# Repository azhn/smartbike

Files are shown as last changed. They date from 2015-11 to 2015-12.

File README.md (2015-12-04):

SMARTBIKE
=====

BLEES
BLEES: Bluetooth Low Energy Environment Sensors.
<br /><br />
BLEES is a 1 inch round sensor tag for sensing the ambient environment. It monitors
temperature, humidity, light, pressure, and movement and reports its readings
over BLE.
<br /><br /><br />

Hardware
--------
The BLEES hardware is a small, once inch round sensor board that mounts onto a [Squall](https://github.com/helena-project/squall) BLE sensor tag. The board 
currently has four sensors:

1. Temperature and Humidity
2. Pressure
3. Light
4. Accelerometer

The BLEES hardware is located in the `hardware` directory, where you can find
the Eagle design files.

Software
--------
The [Squall](https://github.com/helena-project/squall) uses the software located 
in the `software` directory. Follow the directions at [Lab11's Wiki](http://lab11.eecs.umich.edu/wiki/doku.php?id=eecs582w15:setup:start) to 
get your machine set up to build and flash the Squall.

The software sends out the data from the BLEES sensors in BLE advertisements. Specifically,
we encode the data in the "manufacturer data" section of a BLE advertisement and scan response packet.
This means that we do not have to establish a connection between the Squall and a scanning device, 
saving energy by not requiring any devices to pair with the BLEES device, and allowing us to send
the sensor data to many different scanning devices at once.

[Here's a useful BLE Advertisement primer](http://www.argenox.com/bluetooth-low-energy-ble-v4-0-development/library/a-ble-advertising-primer/)

Summon App
-----------
[Summon](https://github.com/lab11/summon) is a UI application for BLE devices.
Rather than requiring every user
to install a new app for every BLE device, Summon allows BLE devices to
point to their own HTML/JS based interface and loads it in a single
application. BLEES supports the summon architecture and provides
a Summon application.

Cloning
-------
To clone both this repository and the required submodules,
clone with the `--recursive` option: 
`git clone --recursive git@github.com:lab11/blees.git`

Otherwise, you can initialize the submodule and keep submodules up to
date by doing `git submodule update --init --recursive`.

If you think all of this is ridiculous and git should just handle submodules automatically, use this:
https://gist.github.com/brghena/fc4483a2df83c47660a5

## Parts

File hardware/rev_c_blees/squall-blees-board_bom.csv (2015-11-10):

# Bill of Materials
# Converted from squall-blees-board_bom.xlsx
# Generated by bom_to_text.py
Qty | Value | Device | Package | Parts | Description | DIGIKEY | MOUSER | NEWARK
5 | 100nF | CAPACITOR | 0402_CAP | C1, C2, C3, C4, C5 | 0402 Capacitor | 1276-1442-6-ND
1 | 10uF | CAPACITOR0603_CAP | 0603_CAP | C6 | 0603 Capacitor | 1276-1119-6-ND
1 | BLUE | LED0603 | LED-0603 | D1 | LEDs | 160-1647-1-ND
2 | SQUALL_HEADER | SQUALL_HEADER | SQUALL_HEADER | J1 | Header for a sensor board on top of the Squall BLE tag board. | H11617CT-ND
2 | HIROSE-DF40C-10DP-0.4V | HIROSE-DF40C-10DP-0.4V | 2X5/SMD/0.4MM | J2, J3 | DF40 Series Header - 0.4MM Pitch | H11616CT-ND | 798-DF40C10DP0.4V51 | 68X2585
1 | 1k | RESISTOR0402_RES | 0402_RES | R1 | 0402 Resistor | RHM1.0KCECT-ND
2 | 10k | RESISTOR0402_RES | 0402_RES | R2, R3 | 0402 Resistor | RHM10.0KCDCT-ND
1 | LPS331APQFN | LPS331APQFN | HCLGA-16L | U1 | LPS331AP pressure sensor |  |  | 52X6707
1 | TSL2561DFN | TSL2561DFN | DFN2 | U2 | TSL2561 light to digital converter | TSL2561-FNDKR-ND
1 | Si7021 | Si7021 | DFN | U3 | Si7021 temperature/humidity sensor | 336-2542-1-ND
1 | ADXL362 | ADXL362 | ADXL362 | U4 | Micropower 3-axis accelerometer | ADXL362BCCZ-R2DKR-ND

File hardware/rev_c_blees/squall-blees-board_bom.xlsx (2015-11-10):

 | Qty | Value | Device | Package | Parts | Description | DIGIKEY | MOUSER | NEWARK
b | 5 | 100nF | CAPACITOR | 0402_CAP | C1, C2, C3, C4, C5 | 0402 Capacitor | 1276-1442-6-ND
b | 1 | 10uF | CAPACITOR0603_CAP | 0603_CAP | C6 | 0603 Capacitor | 1276-1119-6-ND
l | 1 | BLUE | LED0603 | LED-0603 | D1 | LEDs | 160-1647-1-ND
b | 2 | SQUALL_HEADER | SQUALL_HEADER | SQUALL_HEADER | J1 | Header for a sensor board on top of the Squall BLE tag board. | H11617CT-ND
s | 2 | HIROSE-DF40C-10DP-0.4V | HIROSE-DF40C-10DP-0.4V | 2X5/SMD/0.4MM | J2, J3 | DF40 Series Header - 0.4MM Pitch | H11616CT-ND | 798-DF40C10DP0.4V51 | 68X2585
s | 1 | 1k | RESISTOR0402_RES | 0402_RES | R1 | 0402 Resistor | RHM1.0KCECT-ND
b | 2 | 10k | RESISTOR0402_RES | 0402_RES | R2, R3 | 0402 Resistor | RHM10.0KCDCT-ND
b | 1 | LPS331APQFN | LPS331APQFN | HCLGA-16L | U1 | LPS331AP pressure sensor |  |  | 52X6707
b | 1 | TSL2561DFN | TSL2561DFN | DFN2 | U2 | TSL2561 light to digital converter | TSL2561-FNDKR-ND
b | 1 | Si7021 | Si7021 | DFN | U3 | Si7021 temperature/humidity sensor | 336-2542-1-ND
b | 1 | ADXL362 | ADXL362 | ADXL362 | U4 | Micropower 3-axis accelerometer | ADXL362BCCZ-R2DKR-ND
 |  | (b)lees
 |  | (s)quall
 |  | (l)ed box
 |  | (o)bserver
 |  | (x) did not populate

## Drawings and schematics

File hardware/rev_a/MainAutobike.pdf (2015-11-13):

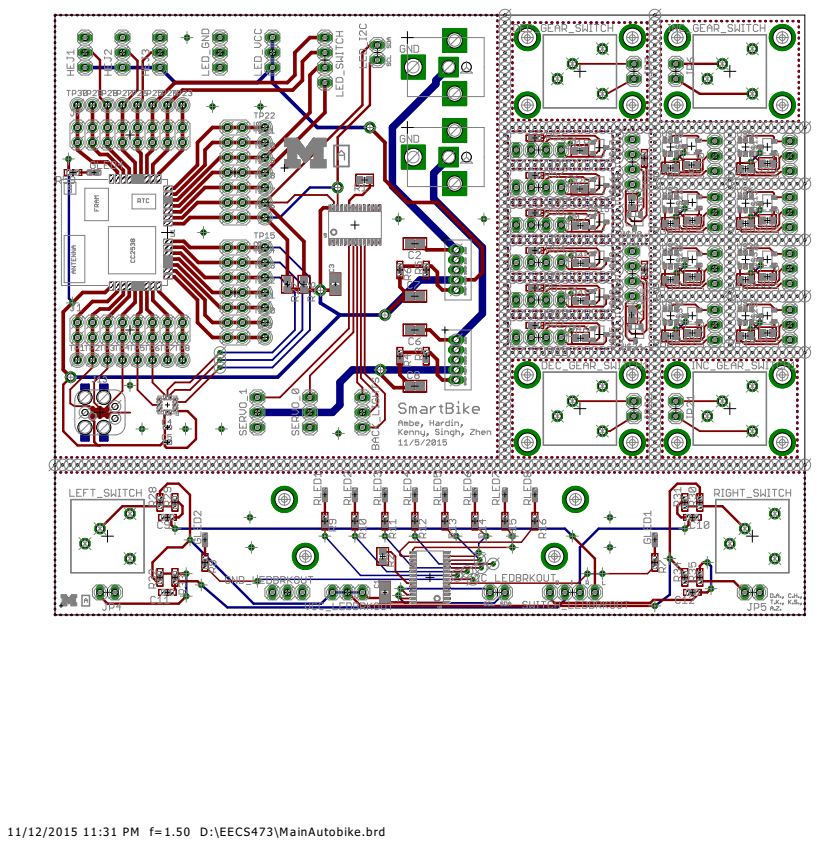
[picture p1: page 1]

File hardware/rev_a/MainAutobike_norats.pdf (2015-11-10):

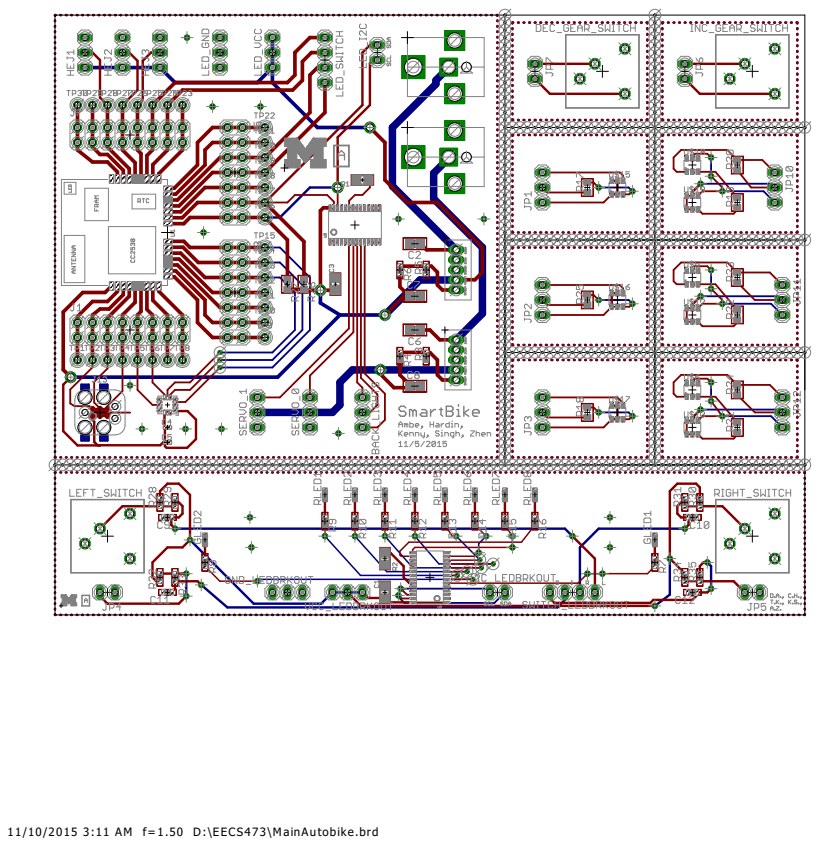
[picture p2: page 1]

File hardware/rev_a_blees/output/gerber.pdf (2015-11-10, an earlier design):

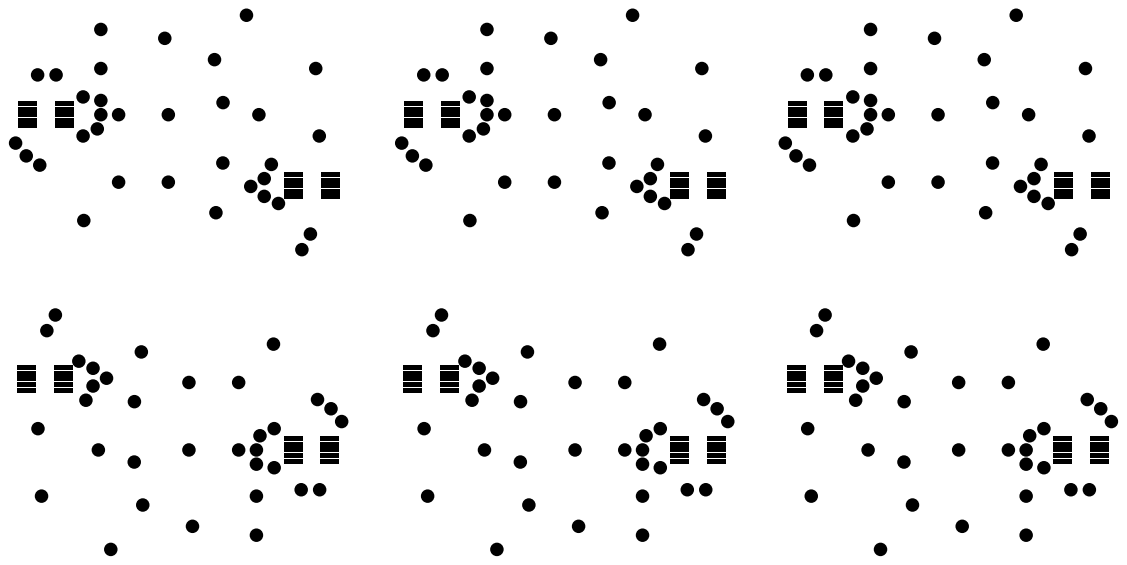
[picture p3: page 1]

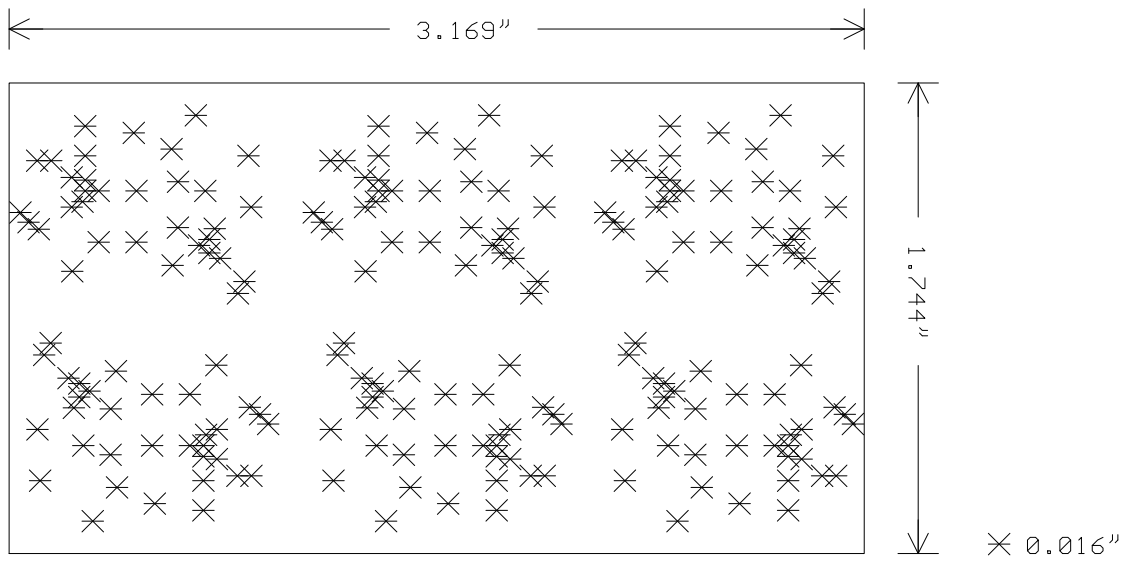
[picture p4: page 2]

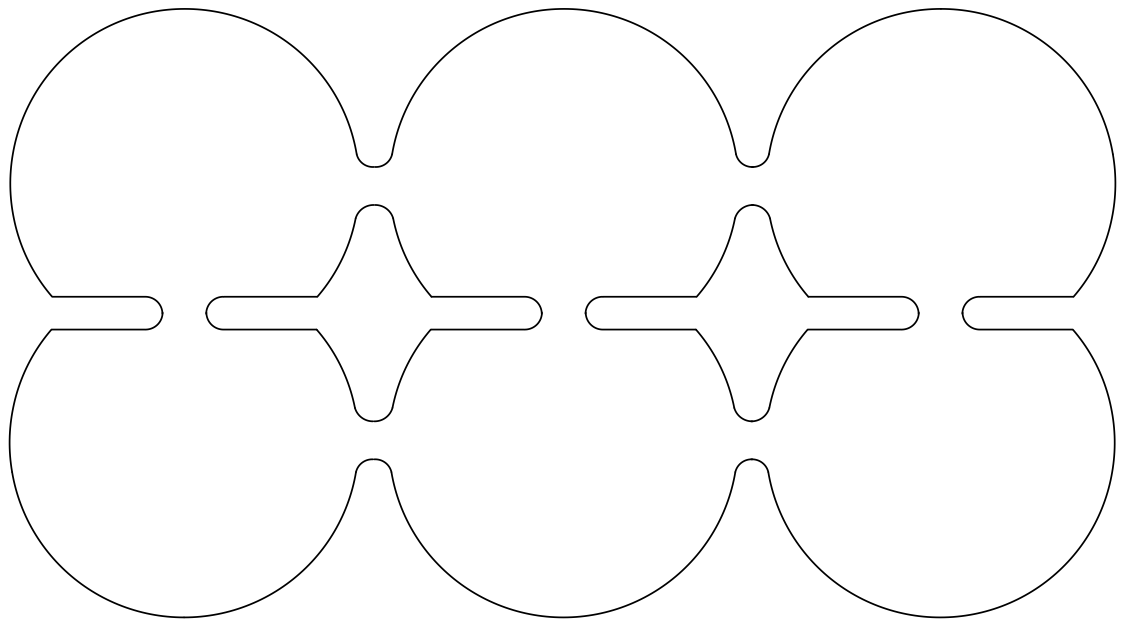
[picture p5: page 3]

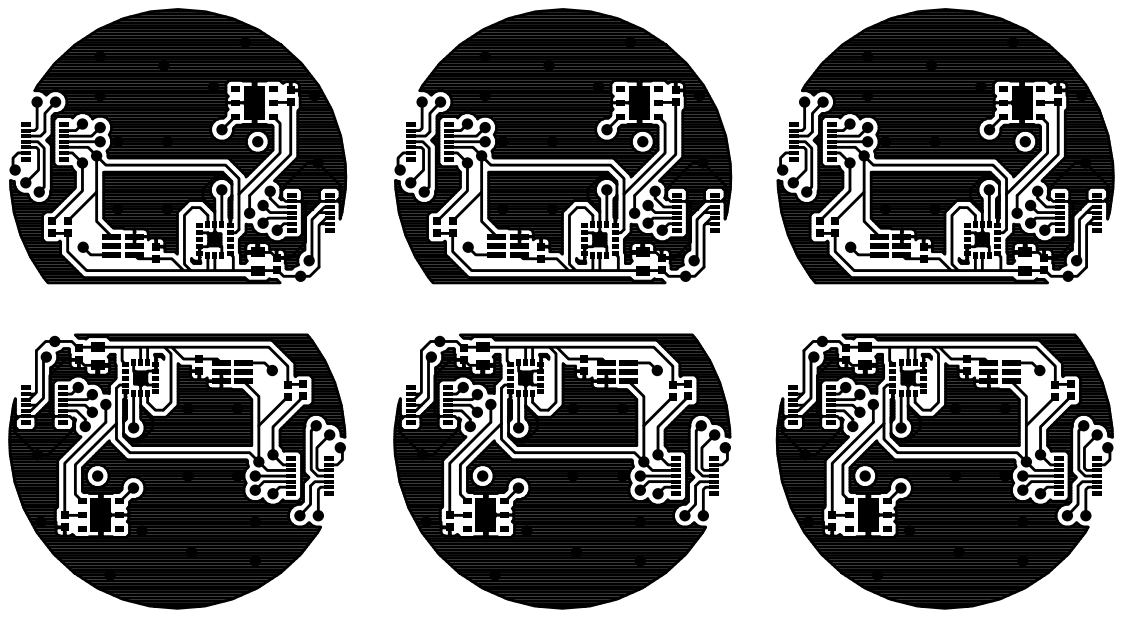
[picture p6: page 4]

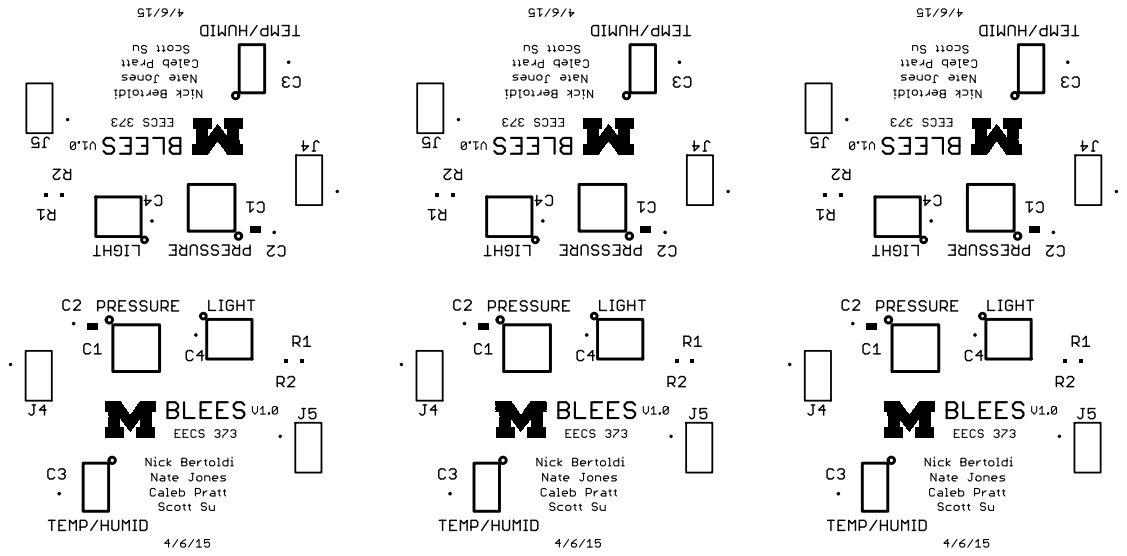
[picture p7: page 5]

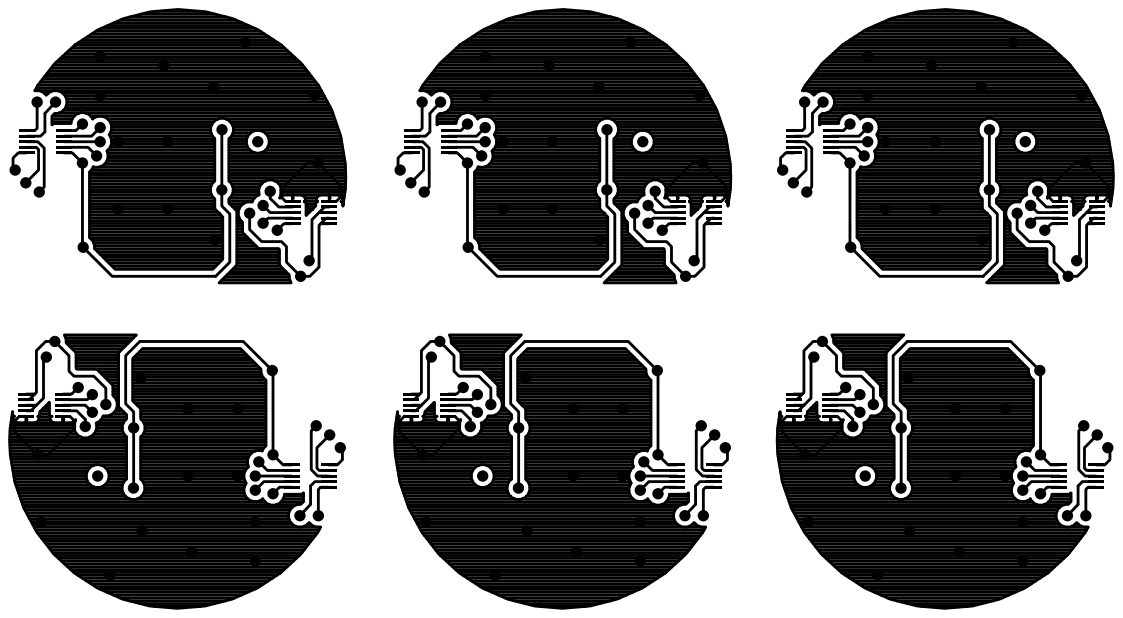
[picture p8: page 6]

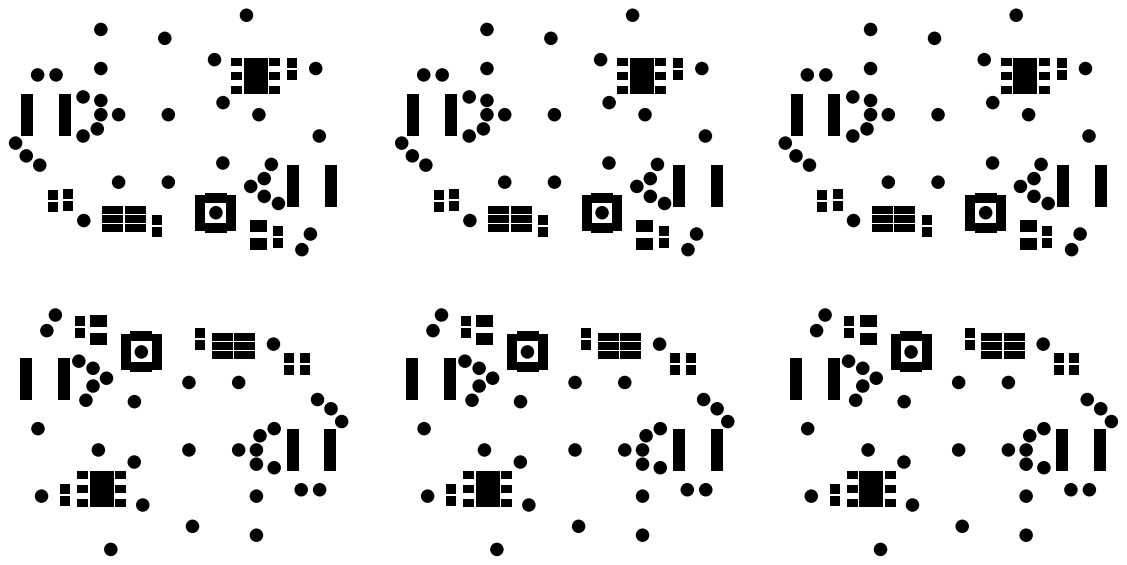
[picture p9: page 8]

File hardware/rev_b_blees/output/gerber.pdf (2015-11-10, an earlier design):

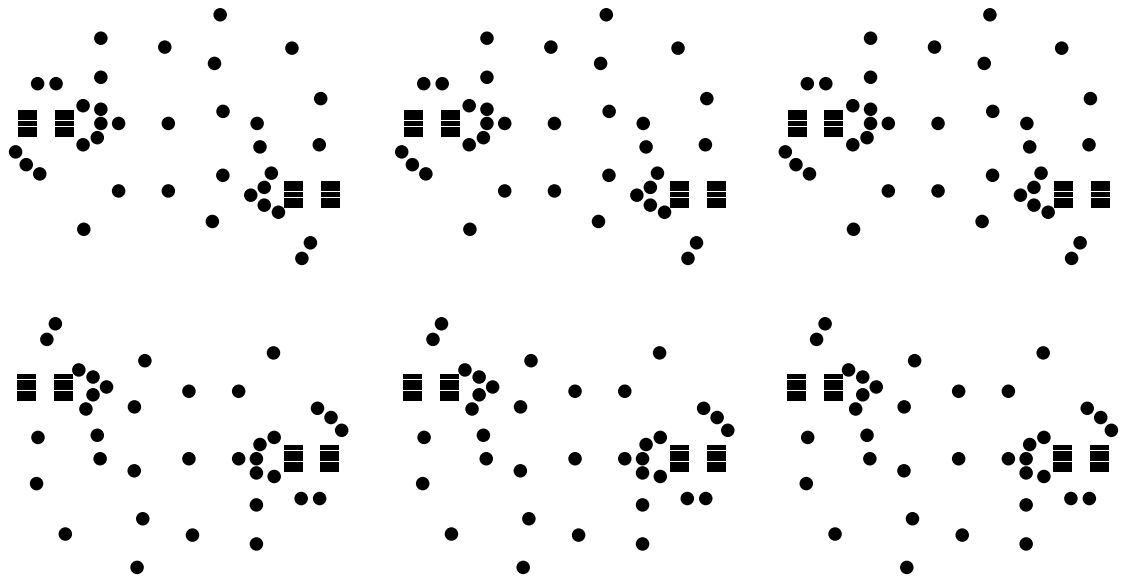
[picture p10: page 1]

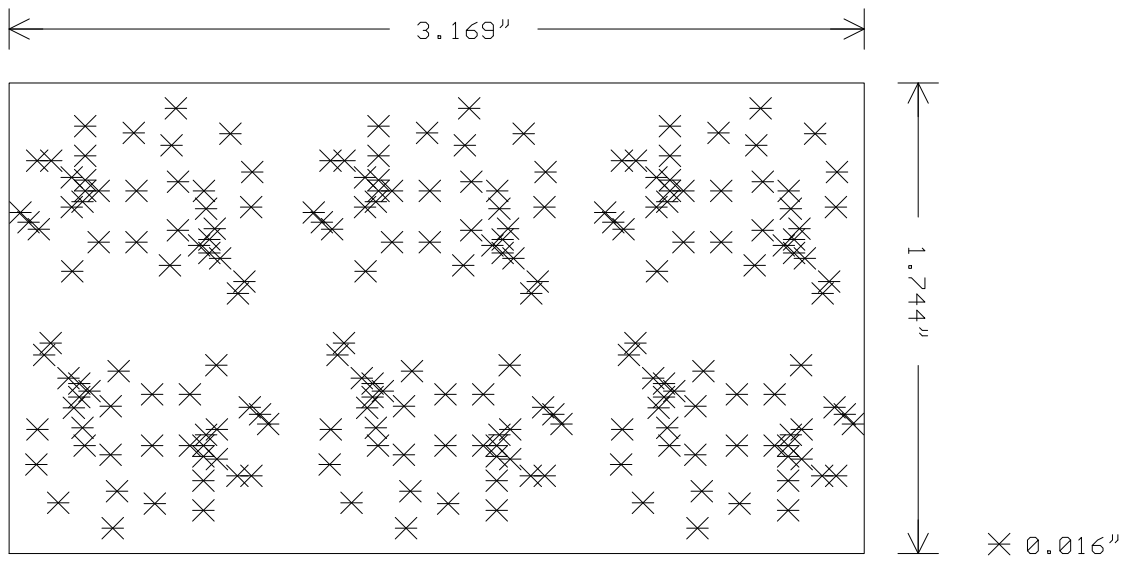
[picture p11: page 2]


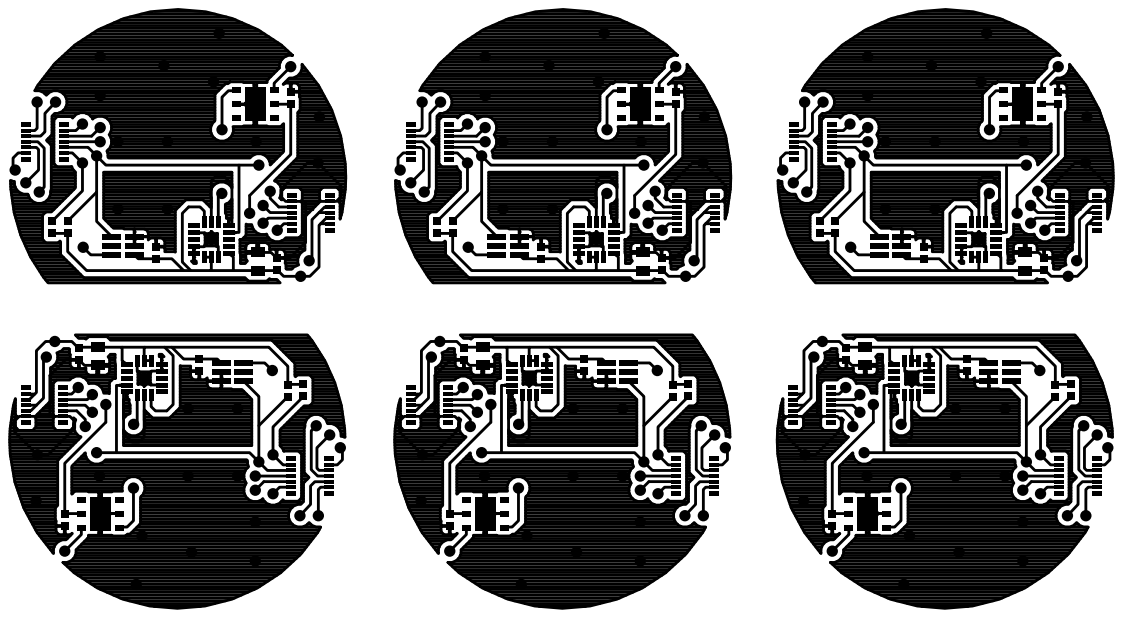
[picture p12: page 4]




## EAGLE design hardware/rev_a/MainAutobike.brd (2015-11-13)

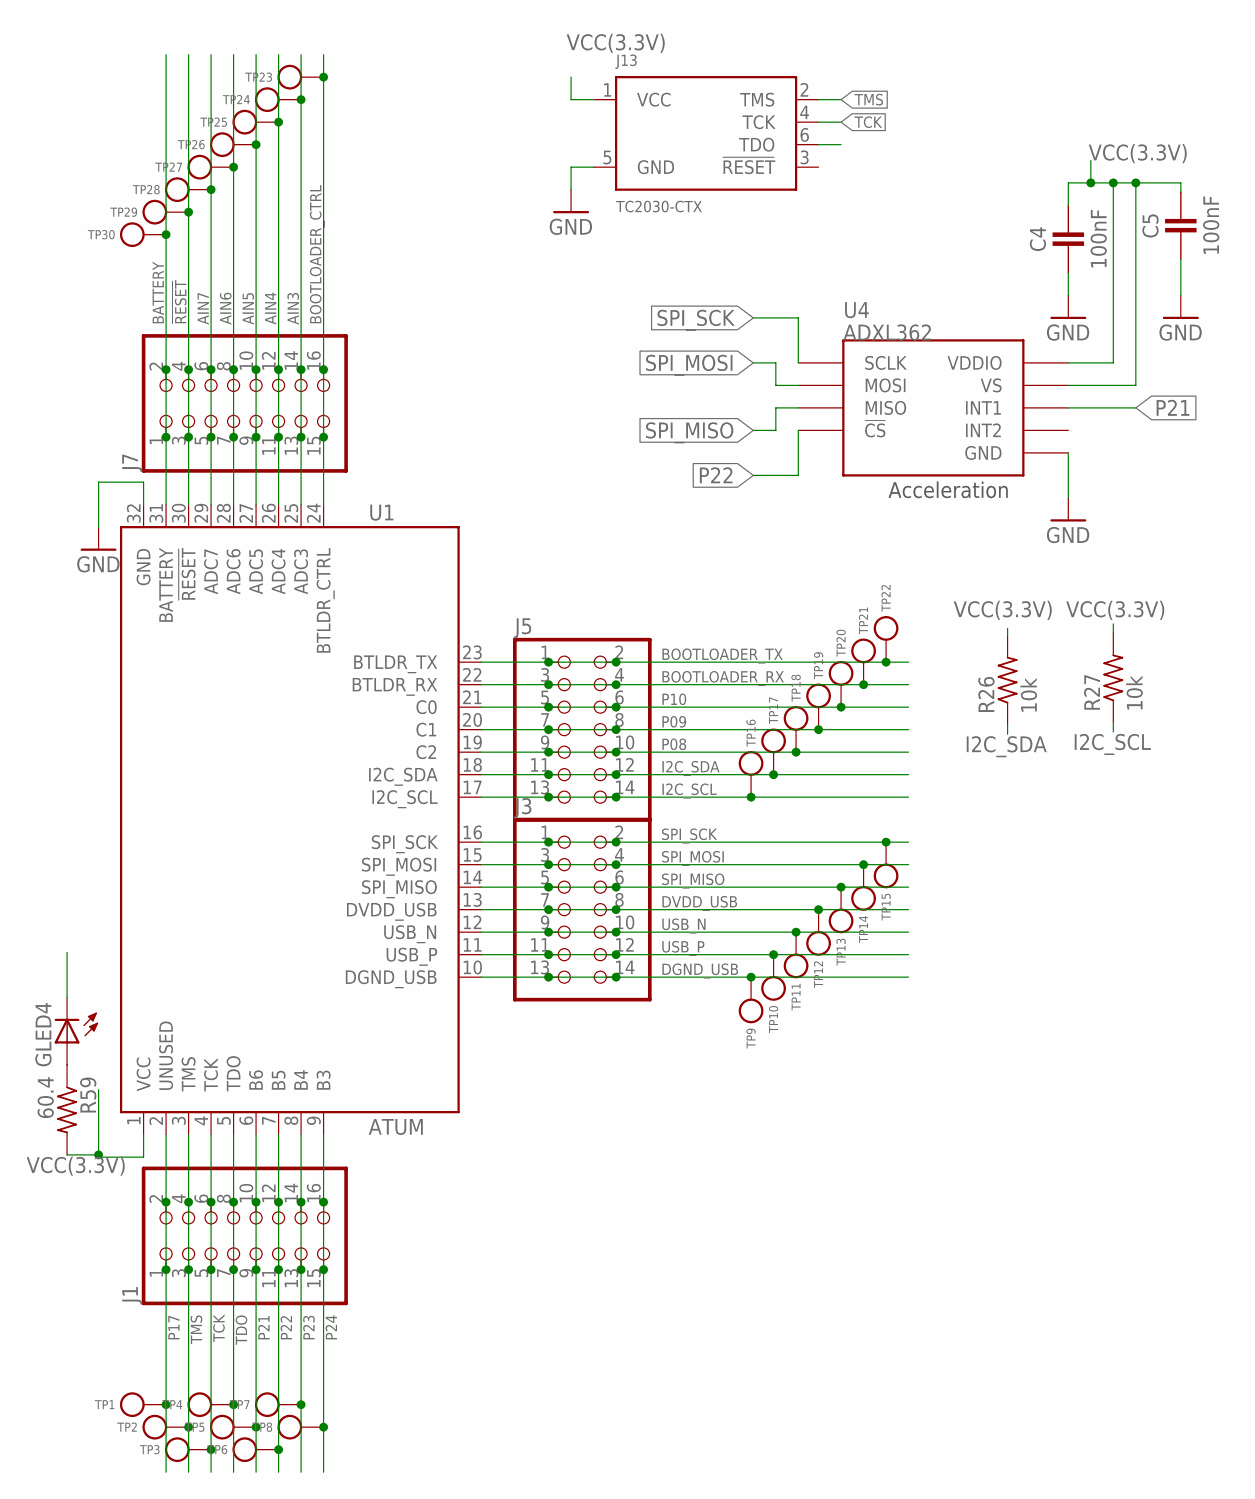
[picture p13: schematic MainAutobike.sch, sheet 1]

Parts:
C4, C5: 100nF; 0402_CAP
GLED4: LEDCHIP-LED0603; CHIP-LED0603
J1, J7: PINHD-2X8; 2X08; DIGIKEY 609-3364-ND
J3, J5: PINHD-2X7; 2X07; DIGIKEY 609-3491-ND
J13: TC2030-CTX; TC2030-IDC
R26, R27: 10k; R0603
R59: 60.4; R0402
TP1, TP2, TP3, TP4, TP5, TP6, TP7, TP8, TP9, TP10, TP11, TP12, TP13, TP14, TP15, TP16, TP17, TP18, TP19, TP20, TP21, TP22, TP23, TP24, TP25, TP26, TP27, TP28, TP29, TP30: TEST_POINT_0.040IN; TESTPOINT_0.040IN
U1: ATUM
U4: ADXL362

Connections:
!RESET: J7.3, J7.4, TP29.TESTPOINT, U1.30 (!RESET)
AIN3: J7.13, J7.14, TP24.TESTPOINT, U1.25 (ADC3); also elsewhere on the board
AIN4: J7.11, J7.12, TP25.TESTPOINT, U1.26 (ADC4); also elsewhere on the board
AIN5: J7.9, J7.10, TP26.TESTPOINT, U1.27 (ADC5); also elsewhere on the board
AIN6: J7.7, J7.8, TP27.TESTPOINT, U1.28 (ADC6); also elsewhere on the board
AIN7: J7.5, J7.6, TP28.TESTPOINT, U1.29 (ADC7); also elsewhere on the board
BATTERY: J7.1, J7.2, TP30.TESTPOINT, U1.31 (BATTERY)
BOOTLOADER_CTRL: J7.15, J7.16, TP23.TESTPOINT, U1.24 (BTLDR_CTRL)
BOOTLOADER_RX: J5.3, J5.4, TP21.TESTPOINT, U1.22 (BTLDR_RX)
BOOTLOADER_TX: J5.1, J5.2, TP22.TESTPOINT, U1.23 (BTLDR_TX)
DGND_USB: J3.13, J3.14, TP9.TESTPOINT, U1.10 (DGND_USB)
DVDD_USB: J3.7, J3.8, TP12.TESTPOINT, U1.13 (DVDD_USB)
GND: C4.2, C5.2, GLED4.C, J13.5 (GND), U1.32 (GND), U4.P$12 (GND), U4.P$13 (GND), U4.P$16 (GND); also elsewhere on the board
I2C_SCL: J5.13, J5.14, R27.1, TP16.TESTPOINT, U1.17 (I2C_SCL); also elsewhere on the board
I2C_SDA: J5.11, J5.12, R26.1, TP17.TESTPOINT, U1.18 (I2C_SDA); also elsewhere on the board
unnamed: GLED4.A, R59.1
P08: J5.9, J5.10, TP18.TESTPOINT, U1.19 (C2)
P09: J5.7, J5.8, TP19.TESTPOINT, U1.20 (C1); also elsewhere on the board
P10: J5.5, J5.6, TP20.TESTPOINT, U1.21 (C0); also elsewhere on the board
P17: J1.1, J1.2, TP1.TESTPOINT, U1.2 (UNUSED)
P21: J1.9, J1.10, TP5.TESTPOINT, U1.6 (B6), U4.P$11 (INT1)
P22: J1.11, J1.12, TP6.TESTPOINT, U1.7 (B5), U4.P$8 (!CS)
P23: J1.13, J1.14, TP7.TESTPOINT, U1.8 (B4)
P24: J1.15, J1.16, TP8.TESTPOINT, U1.9 (B3)
SPI_MISO: J3.5, J3.6, TP13.TESTPOINT, U1.14 (SPI_MISO), U4.P$7 (MISO)
SPI_MOSI: J3.3, J3.4, TP14.TESTPOINT, U1.15 (SPI_MOSI), U4.P$6 (MOSI)
SPI_SCK: J3.1, J3.2, TP15.TESTPOINT, U1.16 (SPI_SCK), U4.P$4 (SCLK)
TCK: J1.5, J1.6, J13.4 (TCK), TP3.TESTPOINT, U1.4 (TCK)
TDO: J1.7, J1.8, J13.6 (TDO), TP4.TESTPOINT, U1.5 (TDO)
TMS: J1.3, J1.4, J13.2 (TMS), TP2.TESTPOINT, U1.3 (TMS)
USB_N: J3.9, J3.10, TP11.TESTPOINT, U1.12 (USB_N)
USB_P: J3.11, J3.12, TP10.TESTPOINT, U1.11 (USB_P)
VCC(3.3V): C4.1, C5.1, J13.1 (VCC), R26.2, R27.2, R59.2, U1.1 (VCC), U4.P$1 (VDDIO), U4.P$14 (VS); also elsewhere on the board

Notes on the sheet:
Acceleration

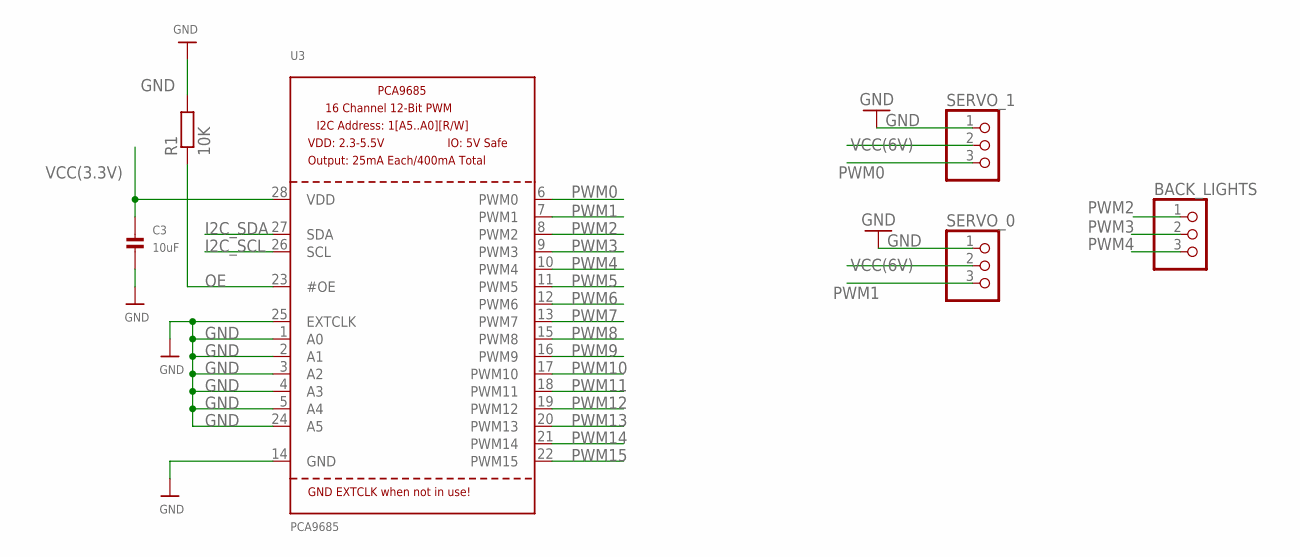
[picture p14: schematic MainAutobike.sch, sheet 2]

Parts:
BACK_LIGHTS: PINHD-1X3; 1X03
C3: 10uF; 0805
R1: 10K; R0603
SERVO_0, SERVO_1: PINHD-1X3; 1X03
U3: PCA9685; TSSOP28

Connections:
GND: C3.2, R1.2, SERVO_0.1, SERVO_1.1, U3.1 (A0), U3.2 (A1), U3.3 (A2), U3.4 (A3), U3.5 (A4), U3.14 (GND), U3.24 (A5), U3.25 (EXTCLK); also elsewhere on the board
I2C_SCL: U3.26 (SCL); also elsewhere on the board
I2C_SDA: U3.27 (SDA); also elsewhere on the board
OE: R1.1, U3.23 (#OE)
PWM0: SERVO_1.3, U3.6 (PWM0)
PWM1: SERVO_0.3, U3.7 (PWM1)
PWM2: BACK_LIGHTS.1, U3.8 (PWM2)
PWM3: BACK_LIGHTS.2, U3.9 (PWM3)
PWM4: BACK_LIGHTS.3, U3.10 (PWM4)
PWM5: U3.11 (PWM5)
PWM6: U3.12 (PWM6)
PWM7: U3.13 (PWM7)
PWM8: U3.15 (PWM8)
PWM9: U3.16 (PWM9)
PWM10: U3.17 (PWM10)
PWM11: U3.18 (PWM11)
PWM12: U3.19 (PWM12)
PWM13: U3.20 (PWM13)
PWM14: U3.21 (PWM14)
PWM15: U3.22 (PWM15)
VCC(3.3V): C3.1, U3.28 (VDD); also elsewhere on the board
VCC(6V): SERVO_0.2, SERVO_1.2; also elsewhere on the board

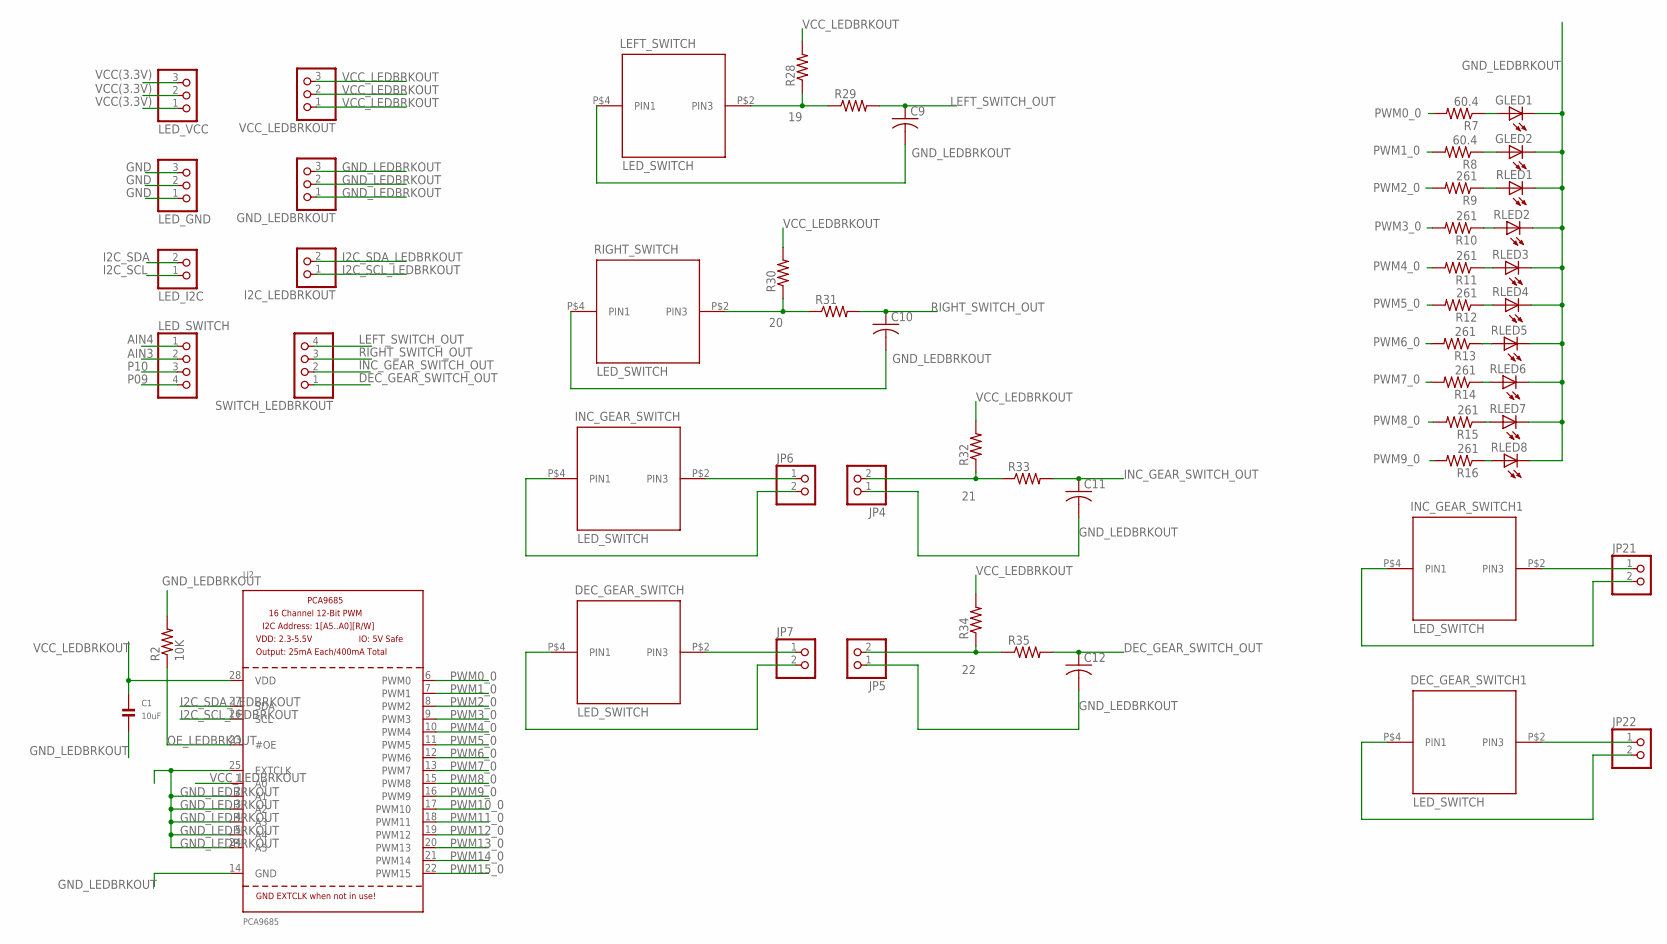
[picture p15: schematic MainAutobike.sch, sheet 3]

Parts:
C1: 10uF; 0805
C9, C10, C11, C12: C-USC0402; C0402
DEC_GEAR_SWITCH, DEC_GEAR_SWITCH1: LED_SWITCH
GLED1, GLED2: LEDCHIP-LED0603; CHIP-LED0603
GND_LEDBRKOUT: PINHD-1X3; 1X03
I2C_LEDBRKOUT: PINHD-1X2; 1X02
INC_GEAR_SWITCH, INC_GEAR_SWITCH1: LED_SWITCH
JP4, JP5, JP6, JP7, JP21, JP22: PINHD-1X2; 1X02
LED_GND: PINHD-1X3; 1X03
LED_I2C: PINHD-1X2; 1X02
LED_SWITCH: PINHD-1X4; 1X04
LED_VCC: PINHD-1X3; 1X03
LEFT_SWITCH: LED_SWITCH
R2: 10K; R0603
R7, R8: 60.4; R0402
R9, R10, R11, R12, R13, R14, R15, R16: 261; R0402
R28, R29, R30, R31, R32, R33, R34, R35: R-US_R0402; R0402
RIGHT_SWITCH: LED_SWITCH
RLED1, RLED2, RLED3, RLED4, RLED5, RLED6, RLED7, RLED8: LEDCHIP-LED0603; CHIP-LED0603
SWITCH_LEDBRKOUT: PINHD-1X4; 1X04
U2: PCA9685; TSSOP28
VCC_LEDBRKOUT: PINHD-1X3; 1X03

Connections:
19: LEFT_SWITCH.P$2 (PIN3), R28.1, R29.1
20: R30.1, R31.1, RIGHT_SWITCH.P$2 (PIN3)
21: JP4.2, R32.1, R33.1
22: JP5.2, R34.1, R35.1
AIN3: LED_SWITCH.2; also elsewhere on the board
AIN4: LED_SWITCH.1; also elsewhere on the board
DEC_GEAR_SWITCH_OUT: C12.1, R35.2, SWITCH_LEDBRKOUT.1
GND: LED_GND.1, LED_GND.2, LED_GND.3; also elsewhere on the board
GND_LEDBRKOUT: C1.2, C9.2, C10.2, C11.2, C12.2, GLED1.C, GLED2.C, GND_LEDBRKOUT.1, GND_LEDBRKOUT.2, GND_LEDBRKOUT.3, JP4.1, JP5.1, LEFT_SWITCH.P$4 (PIN1), R2.2, RIGHT_SWITCH.P$4 (PIN1), RLED1.C, RLED2.C, RLED3.C, RLED4.C, RLED5.C, RLED6.C, RLED7.C, RLED8.C, U2.2 (A1), U2.3 (A2), U2.4 (A3), U2.5 (A4), U2.14 (GND), U2.24 (A5), U2.25 (EXTCLK)
I2C_SCL: LED_I2C.1; also elsewhere on the board
I2C_SCL_LEDBRKOUT: I2C_LEDBRKOUT.1, U2.26 (SCL)
I2C_SDA: LED_I2C.2; also elsewhere on the board
I2C_SDA_LEDBRKOUT: I2C_LEDBRKOUT.2, U2.27 (SDA)
INC_GEAR_SWITCH_OUT: C11.1, R33.2, SWITCH_LEDBRKOUT.2
LEFT_SWITCH_OUT: C9.1, R29.2, SWITCH_LEDBRKOUT.4
unnamed: R16.1, RLED8.A
unnamed: R15.1, RLED7.A
unnamed: R14.1, RLED6.A
unnamed: R13.1, RLED5.A
unnamed: R12.1, RLED4.A
unnamed: R11.1, RLED3.A
unnamed: R10.1, RLED2.A
unnamed: R9.1, RLED1.A
unnamed: GLED2.A, R8.1
unnamed: GLED1.A, R7.1
unnamed: INC_GEAR_SWITCH.P$4 (PIN1), JP6.2
unnamed: INC_GEAR_SWITCH.P$2 (PIN3), JP6.1
unnamed: DEC_GEAR_SWITCH.P$4 (PIN1), JP7.2
unnamed: DEC_GEAR_SWITCH.P$2 (PIN3), JP7.1
unnamed: INC_GEAR_SWITCH1.P$4 (PIN1), JP21.2
unnamed: INC_GEAR_SWITCH1.P$2 (PIN3), JP21.1
unnamed: DEC_GEAR_SWITCH1.P$4 (PIN1), JP22.2
unnamed: DEC_GEAR_SWITCH1.P$2 (PIN3), JP22.1
OE_LEDBRKOUT: R2.1, U2.23 (#OE)
P09: LED_SWITCH.4; also elsewhere on the board
P10: LED_SWITCH.3; also elsewhere on the board
PWM0_0: R7.2, U2.6 (PWM0)
PWM1_0: R8.2, U2.7 (PWM1)
PWM2_0: R9.2, U2.8 (PWM2)
PWM3_0: R10.2, U2.9 (PWM3)
PWM4_0: R11.2, U2.10 (PWM4)
PWM5_0: R12.2, U2.11 (PWM5)
PWM6_0: R13.2, U2.12 (PWM6)
PWM7_0: R14.2, U2.13 (PWM7)
PWM8_0: R15.2, U2.15 (PWM8)
PWM9_0: R16.2, U2.16 (PWM9)
PWM10_0: U2.17 (PWM10)
PWM11_0: U2.18 (PWM11)
PWM12_0: U2.19 (PWM12)
PWM13_0: U2.20 (PWM13)
PWM14_0: U2.21 (PWM14)
PWM15_0: U2.22 (PWM15)
RIGHT_SWITCH_OUT: C10.1, R31.2, SWITCH_LEDBRKOUT.3
VCC(3.3V): LED_VCC.1, LED_VCC.2, LED_VCC.3; also elsewhere on the board
VCC_LEDBRKOUT: C1.1, R28.2, R30.2, R32.2, R34.2, U2.1 (A0), U2.28 (VDD), VCC_LEDBRKOUT.1, VCC_LEDBRKOUT.2, VCC_LEDBRKOUT.3

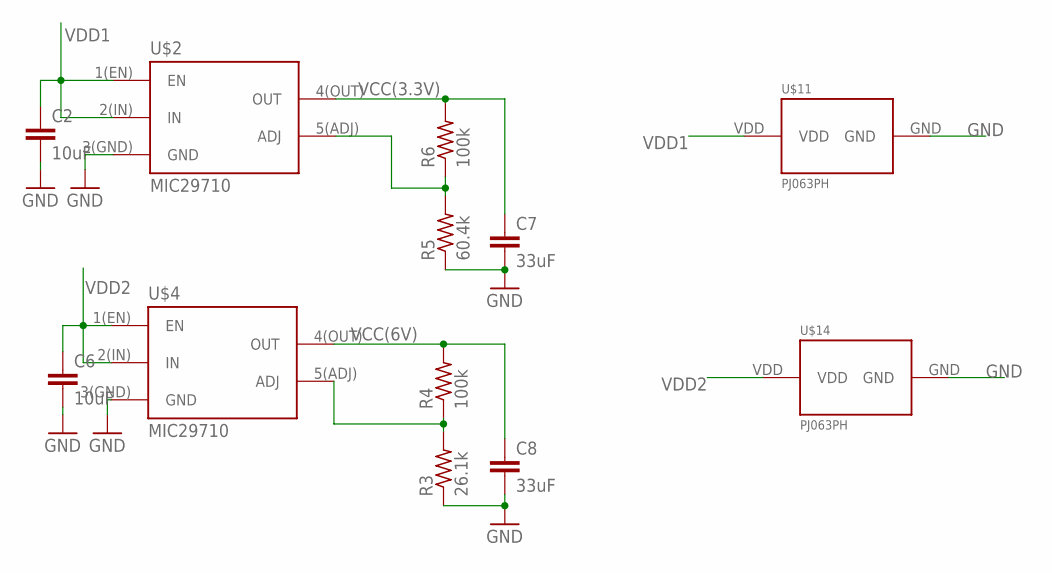
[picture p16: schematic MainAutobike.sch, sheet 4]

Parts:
C2, C6: 10uF; C0805
C7, C8: 33uF; C0805
R3: 26.1k; R0402
R4, R6: 100k; R0402
R5: 60.4k; R0402
U$2, U$4: MIC29710
U$11, U$14: PJ063PH; PJ063BH

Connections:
GND: C2.2, C6.2, C7.2, C8.2, R3.1, R5.1, U$2.3(GND) (GND), U$4.3(GND) (GND), U$11.GND, U$14.GND; also elsewhere on the board
unnamed: R5.2, R6.1, U$2.5(ADJ) (ADJ)
unnamed: R3.2, R4.1, U$4.5(ADJ) (ADJ)
VCC(3.3V): C7.1, R6.2, U$2.4(OUT) (OUT); also elsewhere on the board
VCC(6V): C8.1, R4.2, U$4.4(OUT) (OUT); also elsewhere on the board
VDD1: C2.1, U$2.1(EN) (EN), U$2.2(IN) (IN), U$11.VDD
VDD2: C6.1, U$4.1(EN) (EN), U$4.2(IN) (IN), U$14.VDD

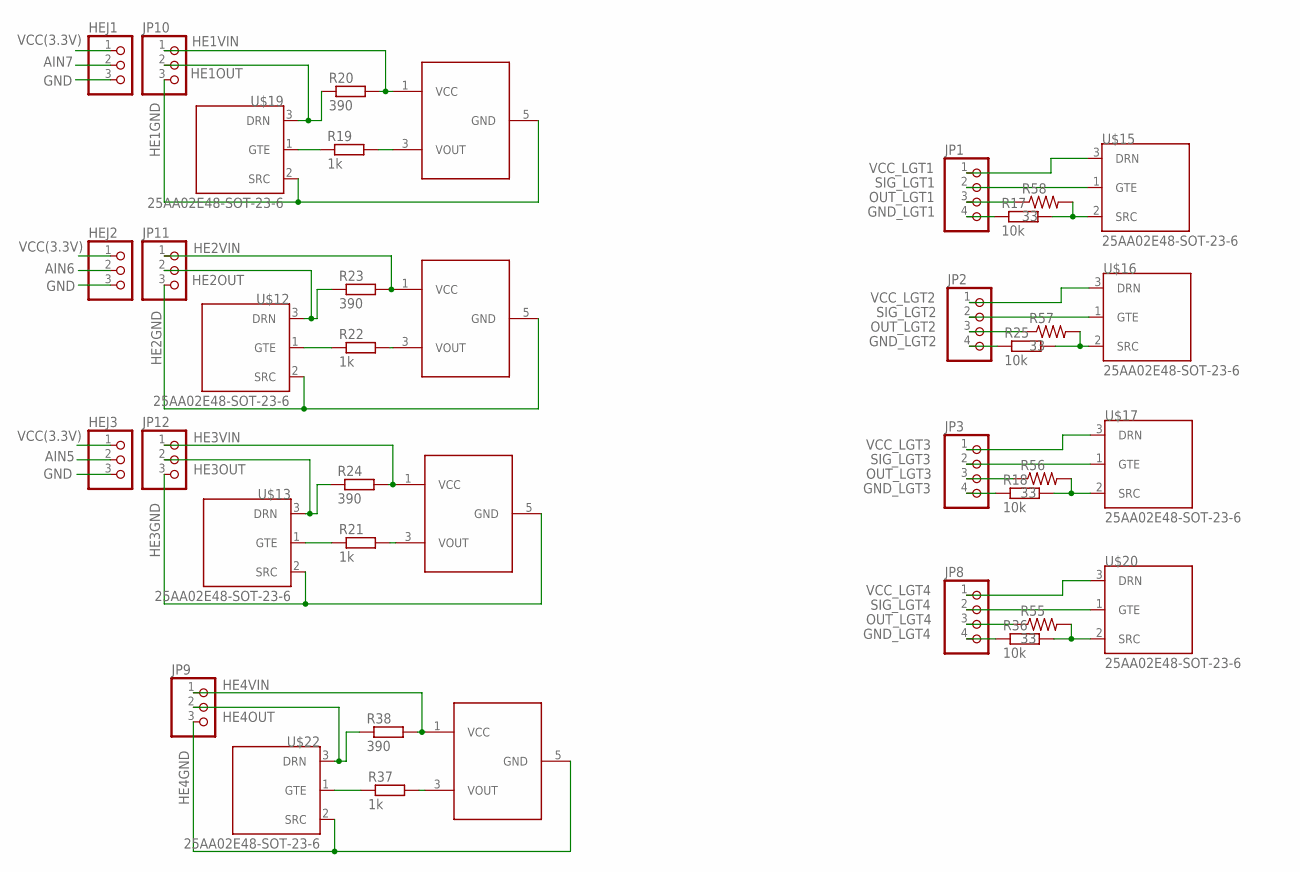
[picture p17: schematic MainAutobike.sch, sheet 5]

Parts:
HEJ1, HEJ2, HEJ3: PINHD-1X3; 1X03
JP1, JP2, JP3, JP8: PINHD-1X4; 1X04
JP9, JP10, JP11, JP12: PINHD-1X3; 1X03
R17, R18, R25, R36: 10k; R0603
R19, R21, R22, R37: 1k; R0603
R20, R23, R24, R38: 390; R0603
R55, R56, R57, R58: 33; R0402
U$5, U$6, U$18, U$21: HALLEFFECT; SOT23-6
U$12, U$13, U$15, U$16, U$17, U$19, U$20, U$22: 25AA02E48-SOT-23-6; SOT23-3

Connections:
AIN5: HEJ3.2; also elsewhere on the board
AIN6: HEJ2.2; also elsewhere on the board
AIN7: HEJ1.2; also elsewhere on the board
GND: HEJ1.3, HEJ2.3, HEJ3.3; also elsewhere on the board
GND_LGT1: JP1.4, R17.1
GND_LGT2: JP2.4, R25.1
GND_LGT3: JP3.4, R18.1
GND_LGT4: JP8.4, R36.1
HE1GND: JP10.3, U$18.5 (GND), U$19.2 (SRC)
HE1OUT: JP10.2, R20.1, U$19.3 (DRN)
HE1VIN: JP10.1, R20.2, U$18.1 (VCC)
HE2GND: JP11.3, U$5.5 (GND), U$12.2 (SRC)
HE2OUT: JP11.2, R23.1, U$12.3 (DRN)
HE2VIN: JP11.1, R23.2, U$5.1 (VCC)
HE3GND: JP12.3, U$6.5 (GND), U$13.2 (SRC)
HE3OUT: JP12.2, R24.1, U$13.3 (DRN)
HE3VIN: JP12.1, R24.2, U$6.1 (VCC)
HE4GND: JP9.3, U$21.5 (GND), U$22.2 (SRC)
HE4OUT: JP9.2, R38.1, U$22.3 (DRN)
HE4VIN: JP9.1, R38.2, U$21.1 (VCC)
unnamed: R37.1, U$22.1 (GTE)
unnamed: R37.2, U$21.3 (VOUT)
unnamed: R19.1, U$19.1 (GTE)
unnamed: R19.2, U$18.3 (VOUT)
unnamed: R21.1, U$13.1 (GTE)
unnamed: R21.2, U$6.3 (VOUT)
unnamed: R22.1, U$12.1 (GTE)
unnamed: R22.2, U$5.3 (VOUT)
unnamed: JP8.3, R55.1
unnamed: JP3.3, R56.1
unnamed: JP2.3, R57.1
unnamed: JP1.3, R58.1
OUT_LGT1: R17.2, R58.2, U$15.2 (SRC)
OUT_LGT2: R25.2, R57.2, U$16.2 (SRC)
OUT_LGT3: R18.2, R56.2, U$17.2 (SRC)
OUT_LGT4: R36.2, R55.2, U$20.2 (SRC)
SIG_LGT1: JP1.2, U$15.1 (GTE)
SIG_LGT2: JP2.2, U$16.1 (GTE)
SIG_LGT3: JP3.2, U$17.1 (GTE)
SIG_LGT4: JP8.2, U$20.1 (GTE)
VCC(3.3V): HEJ1.1, HEJ2.1, HEJ3.1; also elsewhere on the board
VCC_LGT1: JP1.1, U$15.3 (DRN)
VCC_LGT2: JP2.1, U$16.3 (DRN)
VCC_LGT3: JP3.1, U$17.3 (DRN)
VCC_LGT4: JP8.1, U$20.3 (DRN)

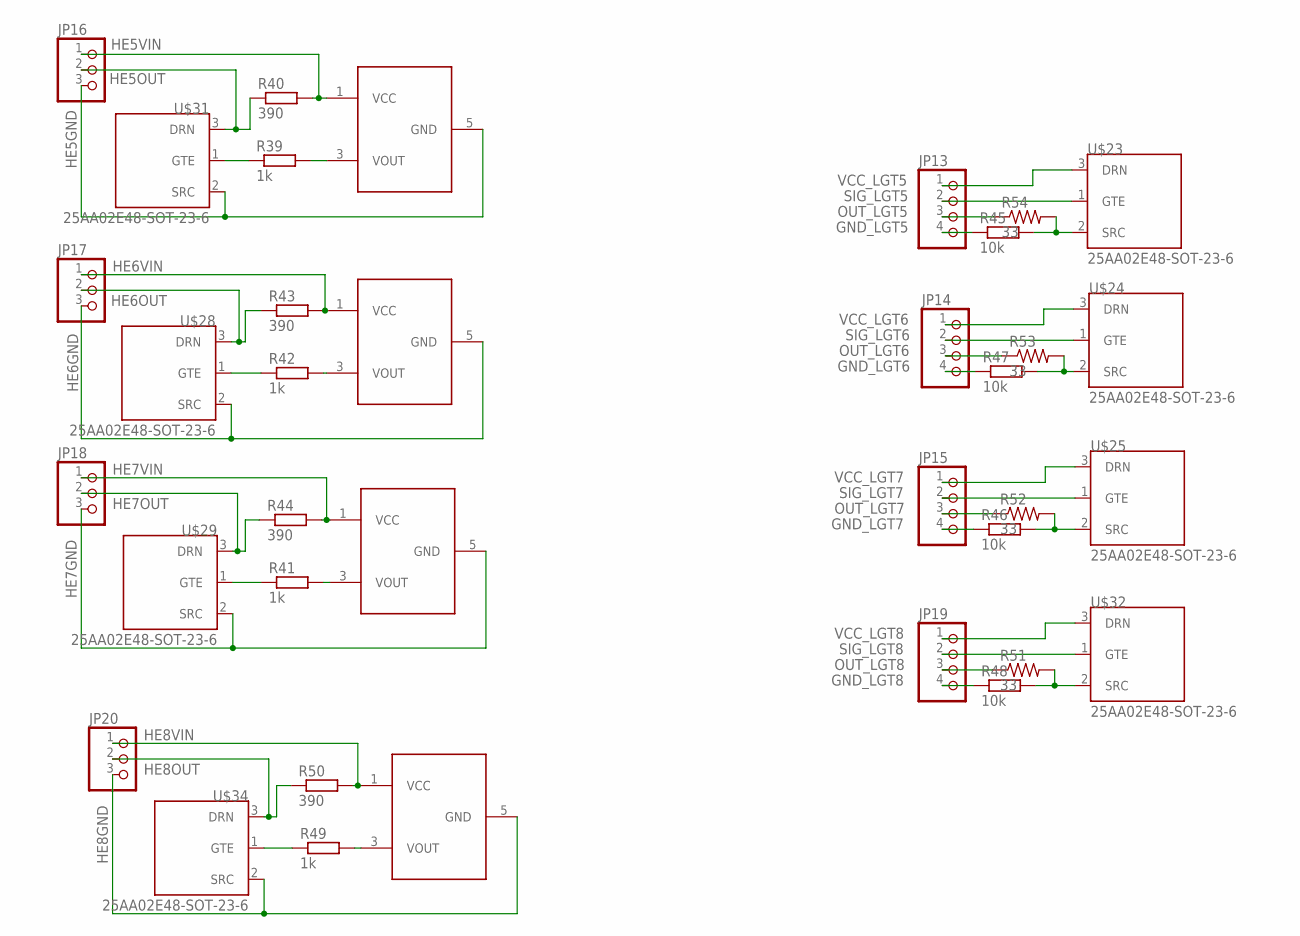
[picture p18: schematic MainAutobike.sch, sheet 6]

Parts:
JP13, JP14, JP15, JP19: PINHD-1X4; 1X04
JP16, JP17, JP18, JP20: PINHD-1X3; 1X03
R39, R41, R42, R49: 1k; R0603
R40, R43, R44, R50: 390; R0603
R45, R46, R47, R48: 10k; R0603
R51, R52, R53, R54: 33; R0402
U$23, U$24, U$25, U$28, U$29, U$31, U$32, U$34: 25AA02E48-SOT-23-6; SOT23-3
U$26, U$27, U$30, U$33: HALLEFFECT; SOT23-6

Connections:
GND_LGT5: JP13.4, R45.1
GND_LGT6: JP14.4, R47.1
GND_LGT7: JP15.4, R46.1
GND_LGT8: JP19.4, R48.1
HE5GND: JP16.3, U$30.5 (GND), U$31.2 (SRC)
HE5OUT: JP16.2, R40.1, U$31.3 (DRN)
HE5VIN: JP16.1, R40.2, U$30.1 (VCC)
HE6GND: JP17.3, U$26.5 (GND), U$28.2 (SRC)
HE6OUT: JP17.2, R43.1, U$28.3 (DRN)
HE6VIN: JP17.1, R43.2, U$26.1 (VCC)
HE7GND: JP18.3, U$27.5 (GND), U$29.2 (SRC)
HE7OUT: JP18.2, R44.1, U$29.3 (DRN)
HE7VIN: JP18.1, R44.2, U$27.1 (VCC)
HE8GND: JP20.3, U$33.5 (GND), U$34.2 (SRC)
HE8OUT: JP20.2, R50.1, U$34.3 (DRN)
HE8VIN: JP20.1, R50.2, U$33.1 (VCC)
unnamed: R39.1, U$31.1 (GTE)
unnamed: R39.2, U$30.3 (VOUT)
unnamed: R41.1, U$29.1 (GTE)
unnamed: R41.2, U$27.3 (VOUT)
unnamed: R42.1, U$28.1 (GTE)
unnamed: R42.2, U$26.3 (VOUT)
unnamed: R49.1, U$34.1 (GTE)
unnamed: R49.2, U$33.3 (VOUT)
unnamed: JP19.3, R51.1
unnamed: JP15.3, R52.1
unnamed: JP14.3, R53.1
unnamed: JP13.3, R54.1
OUT_LGT5: R45.2, R54.2, U$23.2 (SRC)
OUT_LGT6: R47.2, R53.2, U$24.2 (SRC)
OUT_LGT7: R46.2, R52.2, U$25.2 (SRC)
OUT_LGT8: R48.2, R51.2, U$32.2 (SRC)
SIG_LGT5: JP13.2, U$23.1 (GTE)
SIG_LGT6: JP14.2, U$24.1 (GTE)
SIG_LGT7: JP15.2, U$25.1 (GTE)
SIG_LGT8: JP19.2, U$32.1 (GTE)
VCC_LGT5: JP13.1, U$23.3 (DRN)
VCC_LGT6: JP14.1, U$24.3 (DRN)
VCC_LGT7: JP15.1, U$25.3 (DRN)
VCC_LGT8: JP19.1, U$32.3 (DRN)

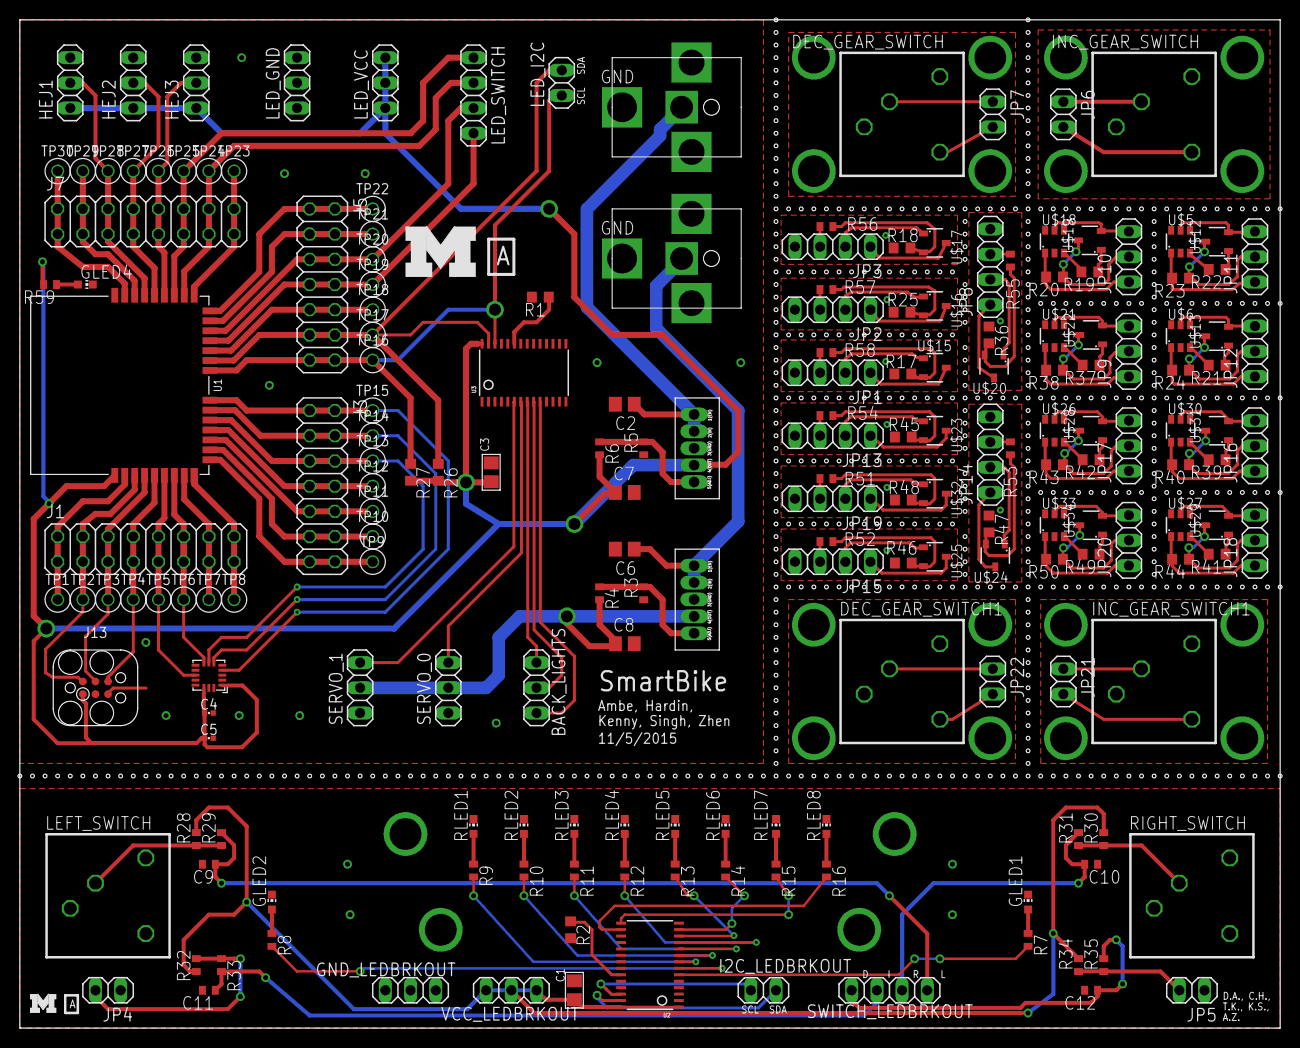
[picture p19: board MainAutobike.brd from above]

Board: 2 copper layers, 127.0 x 101.6 mm, 193 parts (0 on the bottom side), 165 nets.

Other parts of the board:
U$1: UMICH_SOLID_200MIL
U$3: UMICH_SOLID_75MIL

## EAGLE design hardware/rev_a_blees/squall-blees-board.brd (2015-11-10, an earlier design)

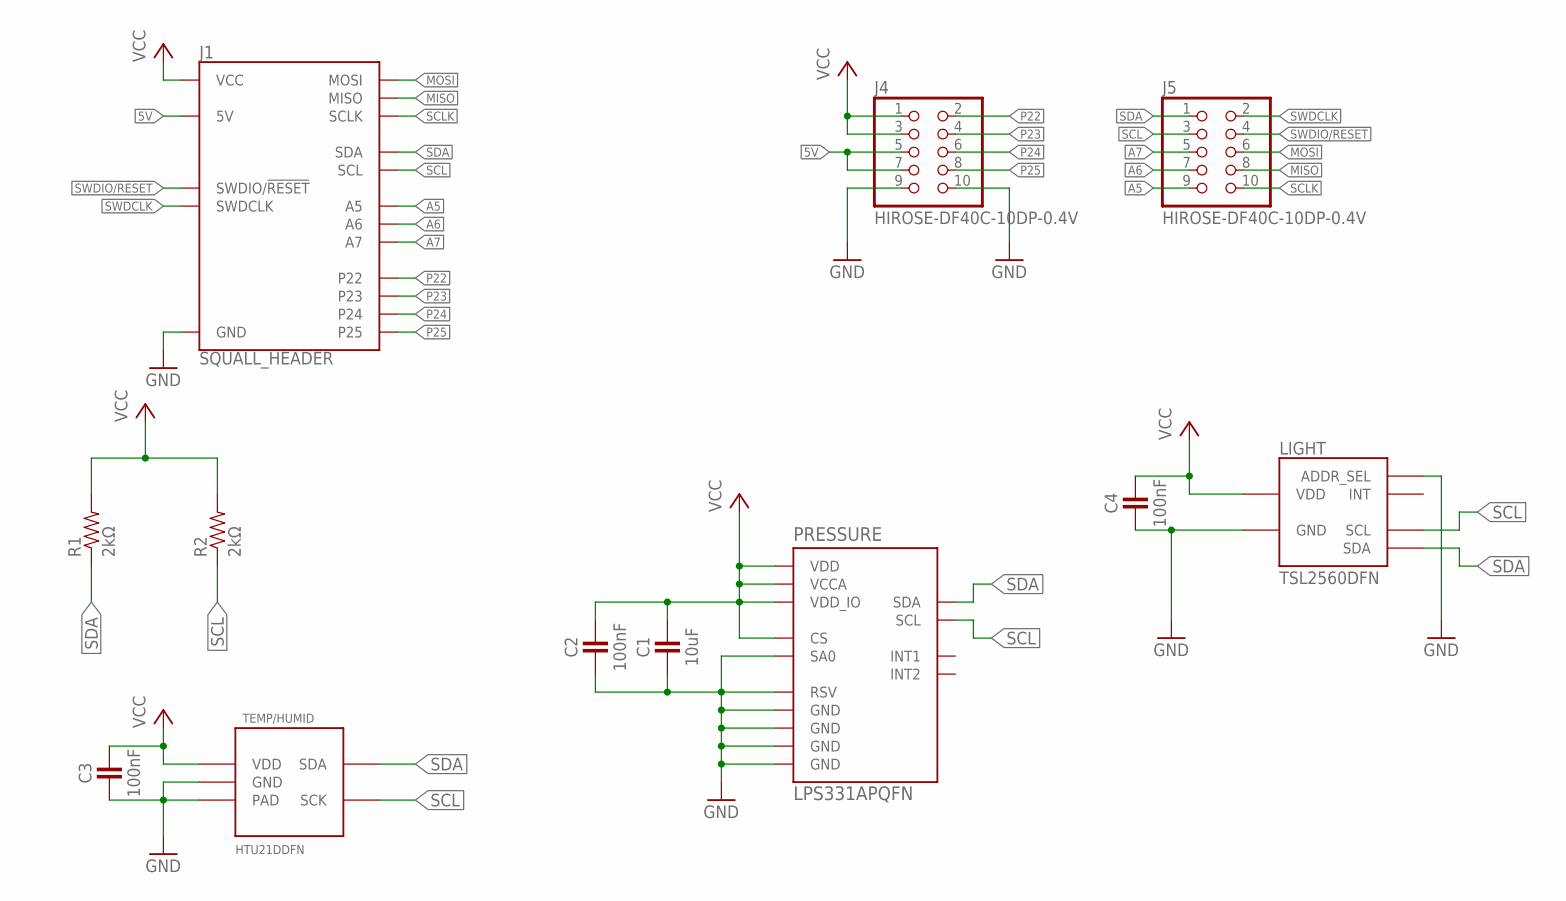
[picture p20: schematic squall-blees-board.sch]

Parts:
C1: 10uF; 0603_CAP
C2, C3, C4: 100nF; 0402_CAP
J1: SQUALL_HEADER
J4, J5: HIROSE-DF40C-10DP-0.4V; 2X5/SMD/0.4MM
LIGHT: TSL2560DFN; DFN2
PRESSURE: LPS331APQFN; HCLGA-16L
R1, R2: 2kΩ; 0402_RES
TEMP/HUMID: HTU21DDFN; DFN

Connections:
5V: J1.A5 (5V), J1.A7 (5V), J4.5, J4.7
A5: J1.B9 (A5), J5.9
A6: J1.B7 (A6), J5.7
A7: J1.B5 (A7), J5.5
GND: C1.2, C2.2, C3.2, C4.2, J1.A9 (GND), J1.A10 (GND), J4.9, J4.10, LIGHT.2 (ADDR_SEL), LIGHT.3 (GND), PRESSURE.5 (GND), PRESSURE.7 (SA0), PRESSURE.10 (RSV), PRESSURE.12 (GND), PRESSURE.13 (GND), PRESSURE.16 (GND), TEMP/HUMID.2 (GND), TEMP/HUMID.PAD
MISO: J1.B8 (MISO), J5.8
MOSI: J1.B6 (MOSI), J5.6
P22: J1.A2 (P22), J4.2
P23: J1.A4 (P23), J4.4
P24: J1.A6 (P24), J4.6
P25: J1.A8 (P25), J4.8
SCL: J1.B3 (SCL), J5.3, LIGHT.4 (SCL), PRESSURE.4 (SCL), R2.1, TEMP/HUMID.6 (SCK)
SCLK: J1.B10 (SCLK), J5.10
SDA: J1.B1 (SDA), J5.1, LIGHT.6 (SDA), PRESSURE.6 (SDA), R1.1, TEMP/HUMID.1 (SDA)
SWDCLK: J1.B2 (SWDCLK), J5.2
SWDIO/!RESET: J1.B4 (SWDIO/!RESET), J5.4
VCC: C1.1, C2.1, C3.1, C4.1, J1.A1 (VCC), J1.A3 (VCC), J4.1, J4.3, LIGHT.1 (VDD), PRESSURE.1 (VDD_IO), PRESSURE.8 (CS), PRESSURE.14 (VDD), PRESSURE.15 (VCCA), R1.2, R2.2, TEMP/HUMID.5 (VDD)

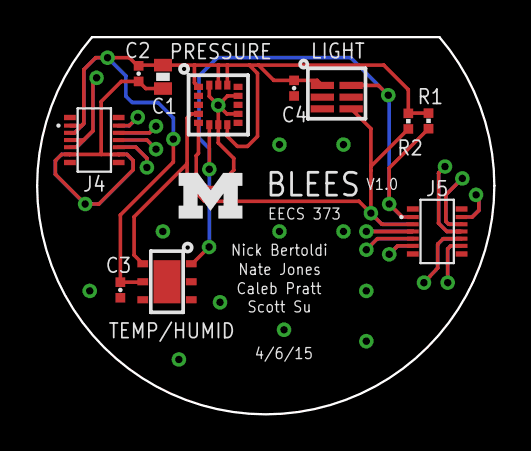
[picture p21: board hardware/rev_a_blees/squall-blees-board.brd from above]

Board: 2 copper layers, 25.4 x 21.0 mm, 12 parts (0 on the bottom side), 17 nets.

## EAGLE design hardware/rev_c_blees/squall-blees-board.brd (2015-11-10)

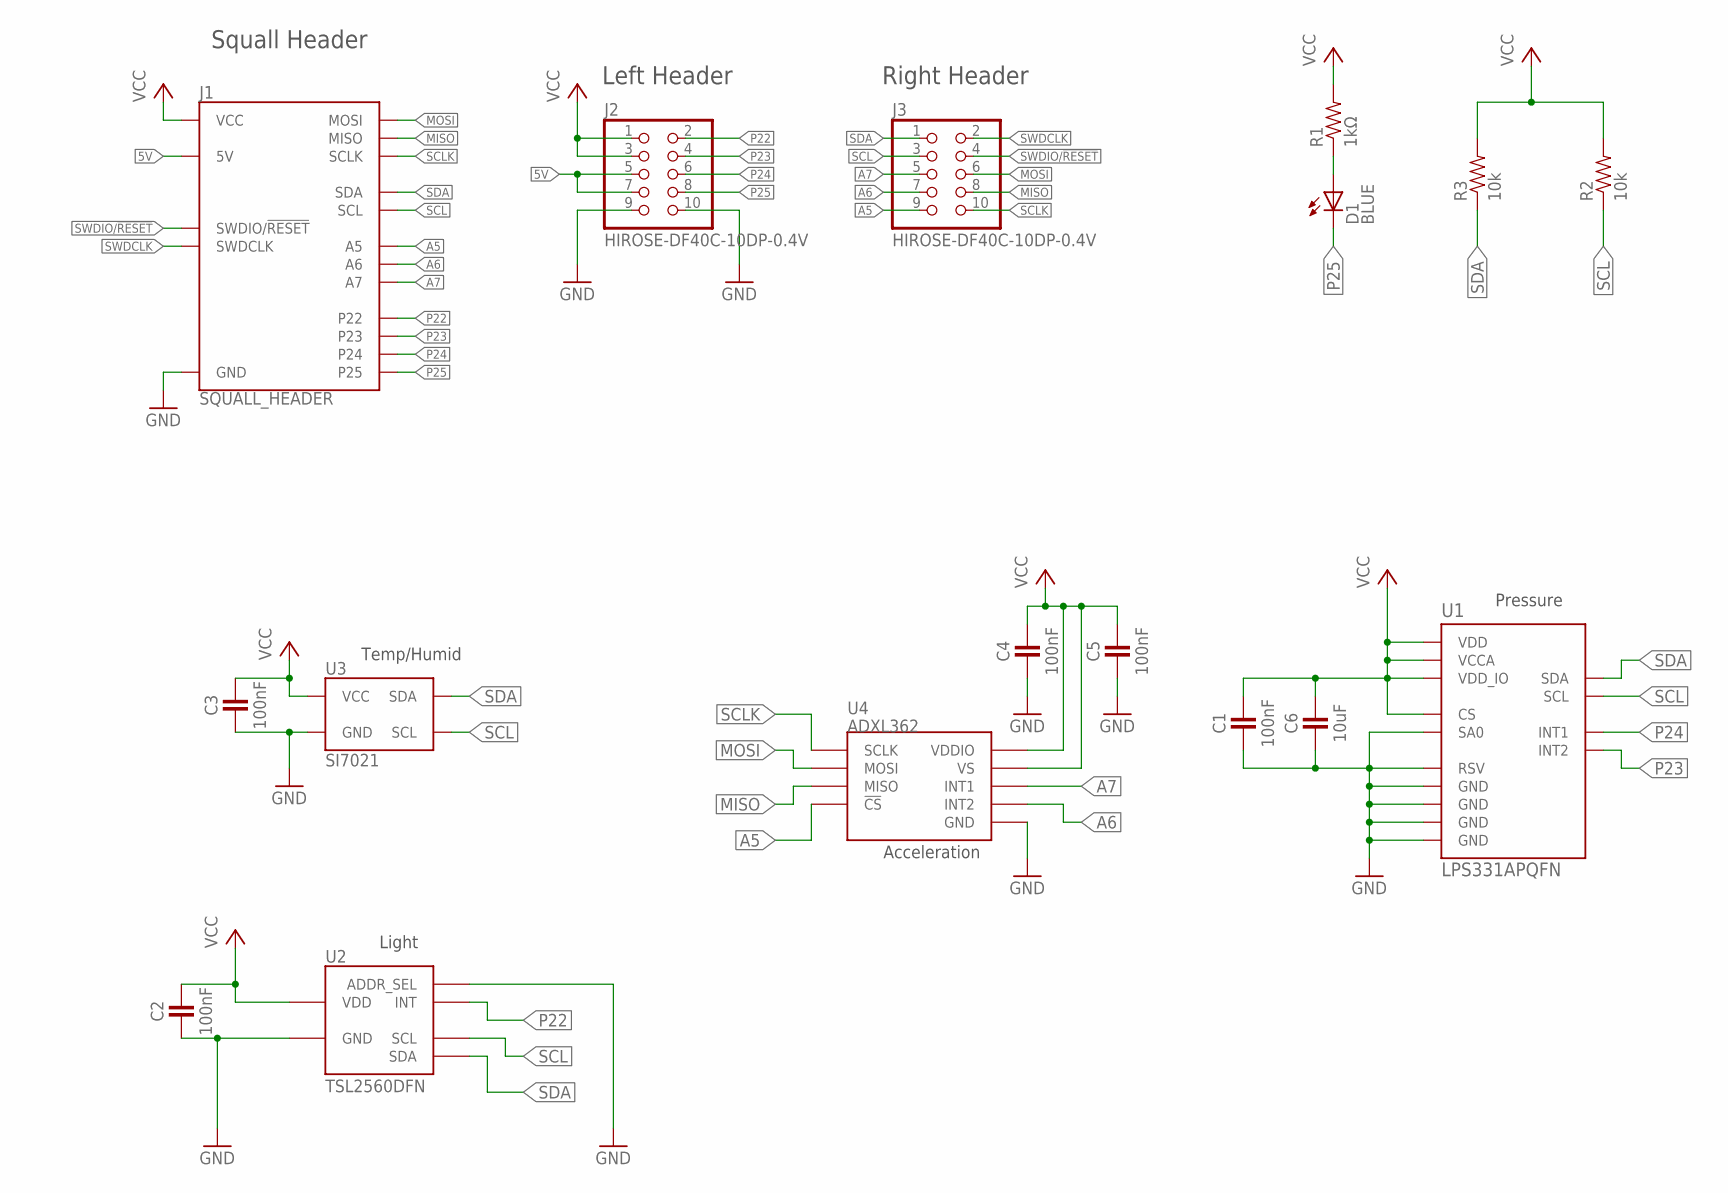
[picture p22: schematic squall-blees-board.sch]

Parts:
C1, C2, C3, C4, C5: 100nF; 0402_CAP
C6: 10uF; 0603_CAP
D1: BLUE; LED-0603
J1: SQUALL_HEADER
J2, J3: HIROSE-DF40C-10DP-0.4V; 2X5/SMD/0.4MM
R1: 1kΩ; 0402_RES
R2, R3: 10k; 0402_RES
U1: LPS331APQFN; HCLGA-16L
U2: TSL2560DFN; DFN2
U3: SI7021; DFN-6/3MM
U4: ADXL362

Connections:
5V: J1.A5 (5V), J1.A7 (5V), J2.5, J2.7
A5: J1.B9 (A5), J3.9, U4.P$8 (!CS)
A6: J1.B7 (A6), J3.7, U4.P$9 (INT2)
A7: J1.B5 (A7), J3.5, U4.P$11 (INT1)
GND: C1.2, C2.2, C3.2, C4.2, C5.2, C6.2, J1.A9 (GND), J1.A10 (GND), J2.9, J2.10, U1.5 (GND), U1.7 (SA0), U1.10 (RSV), U1.12 (GND), U1.13 (GND), U1.16 (GND), U2.2 (ADDR_SEL), U2.3 (GND), U3.2 (GND), U4.P$12 (GND), U4.P$13 (GND), U4.P$16 (GND)
MISO: J1.B8 (MISO), J3.8, U4.P$7 (MISO)
MOSI: J1.B6 (MOSI), J3.6, U4.P$6 (MOSI)
unnamed: D1.A, R1.1
P22: J1.A2 (P22), J2.2, U2.5 (INT)
P23: J1.A4 (P23), J2.4, U1.9 (INT2)
P24: J1.A6 (P24), J2.6, U1.11 (INT1)
P25: D1.C, J1.A8 (P25), J2.8
SCL: J1.B3 (SCL), J3.3, R2.1, U1.4 (SCL), U2.4 (SCL), U3.6 (SCL)
SCLK: J1.B10 (SCLK), J3.10, U4.P$4 (SCLK)
SDA: J1.B1 (SDA), J3.1, R3.1, U1.6 (SDA), U2.6 (SDA), U3.1 (SDA)
SWDCLK: J1.B2 (SWDCLK), J3.2
SWDIO/!RESET: J1.B4 (SWDIO/!RESET), J3.4
VCC: C1.1, C2.1, C3.1, C4.1, C5.1, C6.1, J1.A1 (VCC), J1.A3 (VCC), J2.1, J2.3, R1.2, R2.2, R3.2, U1.1 (VDD_IO), U1.8 (CS), U1.14 (VDD), U1.15 (VCCA), U2.1 (VDD), U3.5 (VCC), U4.P$1 (VDDIO), U4.P$14 (VS)

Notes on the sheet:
Squall Header
Left Header
Right Header
Pressure
Acceleration
Light
Temp/Humid

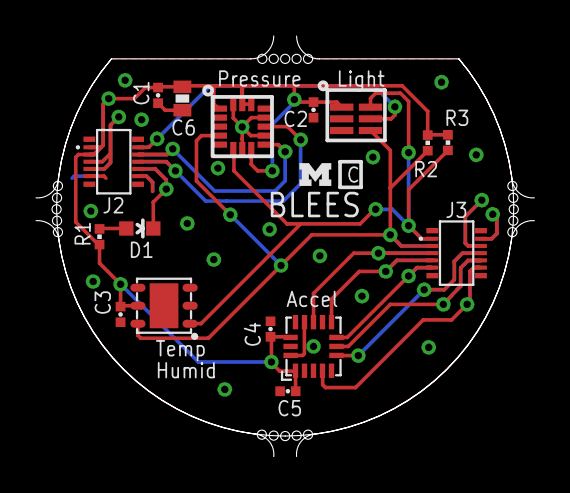
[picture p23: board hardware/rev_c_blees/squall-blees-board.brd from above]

Board: 2 copper layers, 27.7 x 23.4 mm, 18 parts (0 on the bottom side), 18 nets.

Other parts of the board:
U$1: UMICH_SOLID_50MIL

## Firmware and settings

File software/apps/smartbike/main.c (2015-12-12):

/*
 * Smartbike
 *
 *  Dinker Ambe, Charles Hardin, Timothy Kenny, Kunjan Singh, Alan Zhen
 */

/*******************************************************************************
 *   INCLUDES
 ******************************************************************************/
// Standard Libraries
#include <stdint.h>
#include <stdbool.h>
// #include <stdio.h>
// #include <string.h>

// Nordic Libraries
#include "ble.h"
#include "ble_advdata.h"
#include "app_timer.h"
#include "softdevice_handler.h"
#include "nordic_common.h"
// Platform, Peripherals, Devices, Services
#include "nrf_drv_config.h"
#include "smartbike.h"
#include "led.h"
// #include "simple_ble.h"
#include "eddystone.h"
// #include "simple_adv.h"
#include "ble_config.h"

// Drivers
#include "gpio_driver.h"
#include "AccelDataDriver.h"
#include "AccelTurnControl.h"
#include "AccelerometerControl.h"
#include "ServoControl.h"
#include "LightControl.h"
#include "BikeState.h"
#include "HallEffectControl.h"
#include "BikeTimers.h"
#include "LightControl.h"
#include "LightAction.h"
#include "PinStatus.h"

#include "our_service.h"
#include "ble_cscs.h"
// #include "app_timer_appsh.h"
#include "app_scheduler.h"
#include "ble_conn_params.h"
#include "ble_srv_common.h"
#include "ble_hci.h"
#include "nrf51_bitfields.h"


/*******************************************************************************
 *   DEFINES
 ******************************************************************************/
//#define DEVICE_NAME "YITIAN"

// Maximum size is 17 characters
#define PHYSWEB_URL     "goo.gl/XMRl3M"

#define GPIOTE_CHANNEL_0 0
#define GPIOTE_CHANNEL_1 1

// BLE STUFF
#define IS_SRVC_CHANGED_CHARACT_PRESENT 0                                           /**< Include or not the service_changed characteristic. if not enabled, the server's database cannot be changed for the lifetime of the device*/

#define DEVICE_NAME                     "SMARTBIKE"                                /**< Name of device. Will be included in the advertising data. */

#define APP_ADV_INTERVAL                160                                          /**< The advertising interval (in units of 0.625 ms. This value corresponds to 40 ms). */
#define APP_ADV_TIMEOUT_IN_SECONDS      0                                           /**< The advertising timeout (in units of seconds). */

#define APP_TIMER_PRESCALER             0                                           /**< Value of the RTC1 PRESCALER register. */
#define APP_TIMER_MAX_TIMERS            4                                           /**< Maximum number of simultaneously created timers. */
#define APP_TIMER_OP_QUEUE_SIZE         4    

#define BIKE_TIMER_PRESCALER        32  // Value of RTC1 PRESCALER Register
#define BIKE_TIMER_MAX_TIMERS       4   // Maximum number of simultaneous timers
#define BIKE_TIMER_OP_QUEUE_SIZE    4   // Size of timer operation queues                                       /**< Size of timer operation queues. */

#define MIN_CONN_INTERVAL               MSEC_TO_UNITS(500, UNIT_1_25_MS)            /**< Minimum acceptable connection interval (0.5 seconds). */
#define MAX_CONN_INTERVAL               MSEC_TO_UNITS(1000, UNIT_1_25_MS)           /**< Maximum acceptable connection interval (1 second). */
#define SLAVE_LATENCY                   0                                           /**< Slave latency. */
#define CONN_SUP_TIMEOUT                MSEC_TO_UNITS(4000, UNIT_10_MS)             /**< Connection supervisory timeout (4 seconds). */
#define FIRST_CONN_PARAMS_UPDATE_DELAY  APP_TIMER_TICKS(5000, APP_TIMER_PRESCALER)  /**< Time from initiating event (connect or start of notification) to first time sd_ble_gap_conn_param_update is called (5 seconds). */
#define NEXT_CONN_PARAMS_UPDATE_DELAY   APP_TIMER_TICKS(30000, APP_TIMER_PRESCALER) /**< Time between each call to sd_ble_gap_conn_param_update after the first call (30 seconds). */
#define MAX_CONN_PARAMS_UPDATE_COUNT    3                                           /**< Number of attempts before giving up the connection parameter negotiation. */

#define APP_GPIOTE_MAX_USERS            1                                           /**< Maximum number of users of the GPIOTE handler. */

#define BUTTON_DETECTION_DELAY          APP_TIMER_TICKS(50, APP_TIMER_PRESCALER)    /**< Delay from a GPIOTE event until a button is reported as pushed (in number of timer ticks). */

#define SEC_PARAM_BOND                  1                                           /**< Perform bonding. */
#define SEC_PARAM_MITM                  0                                           /**< Man In The Middle protection not required. */
#define SEC_PARAM_IO_CAPABILITIES       BLE_GAP_IO_CAPS_NONE                        /**< No I/O capabilities. */
#define SEC_PARAM_OOB                   0                                           /**< Out Of Band data not available. */
#define SEC_PARAM_MIN_KEY_SIZE          7                                           /**< Minimum encryption key size. */
#define SEC_PARAM_MAX_KEY_SIZE          16                                          /**< Maximum encryption key size. */

static ble_gap_sec_params_t             m_sec_params;                               /**< Security requirements for this application. */
static uint16_t                         m_conn_handle = BLE_CONN_HANDLE_INVALID;    /**< Handle of the current connection. */

static ble_os_t                         m_our_service;
static ble_cscs_t                       m_cscs;
static ble_cscs_init_t                  m_cscs_init;
static ble_cscs_meas_t                  m_cscs_meas;

static ble_gap_adv_params_t             m_adv_params;

#define SCHED_MAX_EVENT_DATA_SIZE       sizeof(app_timer_event_t)                   /**< Maximum size of scheduler events. Note that scheduler BLE stack events do not contain any data, as the events are being pulled from the stack in the event handler. */
#define SCHED_QUEUE_SIZE                10                                          /**< Maximum number of events in the scheduler queue. */


/*******************************************************************************
 *   CONSTANTS
 ******************************************************************************/
const ble_uuid128_t smartbike_uuid128 = {
    {0x04, 0x08, 0x13, 0x8b, 0x13, 0x02, 0x4e, 0x75,
     0x8c, 0xca, 0xc7, 0x5f, 0x70, 0xdf, 0xf8, 0x9f}
};

//our bike
State* bike;

//i2c instance 
nrf_drv_twi_t twi_instance = NRF_DRV_TWI_INSTANCE(1);


/*******************************************************************************
 *   GLOBAL VARIABLES
 ******************************************************************************/
// BLE
ble_uuid_t smartbike_uuid;
// simple_ble_app_t* simple_ble_app;
static ble_app_t app;

// Light Action
LightAction light_act;

// Accelerometer Data
int16_t curr_x_val = 0;

static bool accel_ready = false;

// BLE data
static uint32_t cum_wheel_revs, cum_crank_revs = 0;
static uint16_t  last_wheel_time, last_crank_time = 0;
static bool count_the_wheel_rev = true;

/*******************************************************************************
 *   FUNCTION DECLARATIONS
 ******************************************************************************/


/*******************************************************************************
 *   FUNCTION DEFINITIONS
 ******************************************************************************/

/**@brief Function for the Power manager.
 */
static void power_manage(void)
{
    uint32_t err_code = sd_app_evt_wait();
    APP_ERROR_CHECK(err_code);// Check for errors
}

//********************************* BLE STUFFF***********************
/**@brief Function for the Event Scheduler initialization.*/
static void scheduler_init(void)
{
    APP_SCHED_INIT(SCHED_MAX_EVENT_DATA_SIZE, SCHED_QUEUE_SIZE);
}
/**@brief Function for the GAP initialization.
 *
 * @details This function sets up all the necessary GAP (Generic Access Profile) parameters of the
 *          device including the device name, appearance, and the preferred connection parameters.
 */
static void gap_params_init(void)
{
    uint32_t                err_code;
    
    // Declearing parameter structs. Try to go to the struct definitions to get
    // more information about what parameters they contain
    ble_gap_conn_params_t   gap_conn_params;    // Struct to store GAP connection parameters like max min connection interval etc
    ble_gap_conn_sec_mode_t sec_mode;           // Struct to store security parameters 

    // A simple macro that sets the Security Mode and Level bits in sec_mode
    // to require no protection (open link)
    BLE_GAP_CONN_SEC_MODE_SET_OPEN(&sec_mode);

    // Store the device name and security mode in the SoftDevice. Our name is defined to "HelloWorld" in the beginning of this file
    err_code = sd_ble_gap_device_name_set(&sec_mode,
                                          (const uint8_t *)DEVICE_NAME,
                                          strlen(DEVICE_NAME));
    APP_ERROR_CHECK(err_code);// Check for errors

    // Always initialize all fields in structs to zero or you might get unexpected behaviour
    memset(&gap_conn_params, 0, sizeof(gap_conn_params));

    // Populate the GAP connection parameter struct
    gap_conn_params.min_conn_interval = MIN_CONN_INTERVAL;
    gap_conn_params.max_conn_interval = MAX_CONN_INTERVAL;
    gap_conn_params.slave_latency     = SLAVE_LATENCY;
    gap_conn_params.conn_sup_timeout  = CONN_SUP_TIMEOUT;

    // Set GAP Peripheral Preferred Connection Parameters
    // The device use these prefered values when negotiating connection terms with another device
    err_code = sd_ble_gap_ppcp_set(&gap_conn_params);
    APP_ERROR_CHECK(err_code);// Check for errors
                                            
    // Set appearence                                         
    //sd_ble_gap_appearance_set(BLE_APPEARANCE_HID_MOUSE);
    sd_ble_gap_appearance_set(0);
    APP_ERROR_CHECK(err_code);// Check for errors
}


/**@brief Function for initializing the Advertising functionality.
 *
 * @details Encodes the required advertising data and passes it to the stack.
 *          Also builds a structure to be passed to the stack when starting advertising.
 */
static void advertising_init(void)
{
    uint32_t            err_code;
    ble_advdata_t       advdata;    // Struct containing advertising parameters
    uint8_t             flags       = BLE_GAP_ADV_FLAGS_LE_ONLY_GENERAL_DISC_MODE; // Defines how your device is seen (or not seen) by other devices
    ble_uuid_t          adv_uuids[] = {{0x1816, BLE_UUID_TYPE_BLE}};    // Random example User Unique Identifier
  

    /* commented out so can fit full device name in advertisement
       manufacturer data set in scan response instead
    ble_advdata_manuf_data_t        manuf_data;
    uint8_t data[]                  = "SomeData!";
    manuf_data.company_identifier   = 0x0059;
    manuf_data.data.p_data          = data;
    manuf_data.data.size            = sizeof(data);   
    */
 
    // Populate the advertisement packet
    // Always initialize all fields in structs to zero or you might get unexpected behaviour
    memset(&advdata, 0, sizeof(advdata));
    
    advdata.name_type               = BLE_ADVDATA_FULL_NAME;
    advdata.include_appearance      = false;
    //advdata.short_name_len          = 6;                                             
    advdata.flags                   = flags;                                     // Must be included, but not discussed in this tutorial
    advdata.uuids_complete.uuid_cnt = sizeof(adv_uuids) / sizeof(adv_uuids[0]); // Must be included, but not discussed in this tutorial
    advdata.uuids_complete.p_uuids  = adv_uuids;                                // Must be included, but not discussed in this tutorial
    
    // commented out so can fit full device name in advertisement
    // manufacturer data is set in scan response instead
    //advdata.p_manuf_specific_data  = &manuf_data;
   
    
    /*ble_advdata_manuf_data_t                manuf_data_response;
    uint8_t dataresponse[]                  = "LotsOfWords";
    manuf_data_response.company_identifier  = 0x0059;
    manuf_data_response.data.p_data         = dataresponse;
    manuf_data_response.data.size           = sizeof(dataresponse);
    */ 

    ble_uuid_t  m_adv_uuids[] = {{BLE_UUID_OUR_SERVICE, BLE_UUID_TYPE_VENDOR_BEGIN}};

    ble_advdata_t                           advdata_response;
    
    // always initialize all fields in structs to zero or else might get unexpected behavior
    memset(&advdata_response, 0, sizeof(advdata_response));
    // populate scan response packet
    //advdata_response.name_type              = BLE_ADVDATA_NO_NAME;
    //advdata_response.p_manuf_specific_data  = &manuf_data_response;
    
    advdata_response.uuids_complete.uuid_cnt = sizeof(m_adv_uuids) / sizeof(m_adv_uuids[0]);
    advdata_response.uuids_complete.p_uuids  = m_adv_uuids;

    // Set the advertisement and scan response packet. 
    err_code = ble_advdata_set(&advdata, NULL);
    APP_ERROR_CHECK(err_code);// Check for errors
}



/**@brief Function for initializing security parameters.
 */
static void sec_params_init(void)
{
    m_sec_params.bond         = SEC_PARAM_BOND;
    m_sec_params.mitm         = SEC_PARAM_MITM;
    m_sec_params.io_caps      = SEC_PARAM_IO_CAPABILITIES;
    m_sec_params.oob          = SEC_PARAM_OOB;
    m_sec_params.min_key_size = SEC_PARAM_MIN_KEY_SIZE;
    m_sec_params.max_key_size = SEC_PARAM_MAX_KEY_SIZE;
}
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
int main(void) {

	/*********************************************************/
	/*               Local Variables/Data                    */
	/*********************************************************/
	uint32_t err_code;
	uint32_t curr_time;
	//create our state
	// Do not remove any of the create_state functions
	// We need them to fix an interrupt bug
	bike = create_state();


	/*    bool button09 = false, button10 = false, 
		  button06 = false, button05 = false, button04 = false,
		  button03 = false;*/
	/*********************************************************/
	/*                  Initialize Lights                    */
	/*********************************************************/
	// Initialization of LEDs (two methods)
	led_init(LED_0);
	led_init(LED_1);
	led_init(LED_2);
	//  OR
	// nrf_gpio_cfg_output(LED_0);  //Configure LED 0 as output
	// nrf_gpio_cfg_output(LED_1);  //Configure LED 1 as output


	/*********************************************************/
	/*                 Initialize GPIO                       */
	/*********************************************************/
	// TODO: change pin polarity and pull configs
	gpio_cfg_t cfgs[] = {
		{bike->pin_mappings[WHEEL_FLAG], GPIO_ACTIVE_HIGH, NRF_GPIO_PIN_NOPULL, &gpiote_handler, PIN_GPIOTE_IN},
		{bike->pin_mappings[PEDAL_FLAG], GPIO_ACTIVE_HIGH, NRF_GPIO_PIN_NOPULL, &gpiote_handler, PIN_GPIOTE_IN},
		{bike->pin_mappings[SHIFT_UP_FLAG], GPIO_ACTIVE_LOW, NRF_GPIO_PIN_NOPULL, &port_event_handler, PIN_PORT_IN},
		{bike->pin_mappings[SHIFT_DOWN_FLAG], GPIO_ACTIVE_LOW, NRF_GPIO_PIN_NOPULL, &port_event_handler, PIN_PORT_IN},
		{bike->pin_mappings[LEFT_TURN_FLAG], GPIO_ACTIVE_LOW, NRF_GPIO_PIN_NOPULL, &port_event_handler, PIN_PORT_IN},
		{bike->pin_mappings[RIGHT_TURN_FLAG], GPIO_ACTIVE_LOW, NRF_GPIO_PIN_NOPULL, &port_event_handler, PIN_PORT_IN},
		{bike->pin_mappings[MANUAL_MODE_SWITCH_FLAG], GPIO_ACTIVE_TOGGLE, NRF_GPIO_PIN_NOPULL, &port_event_handler, PIN_PORT_IN},
		{bike->pin_mappings[HANDLE_RIGHT_TURN_FLAG], GPIO_ACTIVE_TOGGLE , NRF_GPIO_PIN_NOPULL, &port_event_handler, PIN_PORT_IN},
		{bike->pin_mappings[HANDLE_LEFT_TURN_FLAG], GPIO_ACTIVE_TOGGLE , NRF_GPIO_PIN_NOPULL, &port_event_handler, PIN_PORT_IN}
		/*{23, GPIO_ACTIVE_TOGGLE , NRF_GPIO_PIN_NOPULL, &port_event_handler, PIN_OUT}*/
	};

	uint8_t gpio_cfg_count;
	gpio_cfg_count = 9;

	err_code = gpio_init(cfgs, gpio_cfg_count);
	APP_ERROR_CHECK(err_code);

	gpio_input_enable_all();

        /*********************************************************/
	/*                  Reset Bike States                    */
	/*********************************************************/
	reset_bike_state(bike);

	/*********************************************************/
	/*                  Initialize Timers                    */
	/*********************************************************/
	// Setup and start timer
	set_accel_handler(timer_handler);
	//set_turn_signal_handler(timer_handler2);
	set_ble_handler(timer_handler3);

	timers_app_init();

	// Setup clock
	SOFTDEVICE_HANDLER_INIT(NRF_CLOCK_LFCLKSRC_RC_250_PPM_8000MS_CALIBRATION, false);

	/*********************************************************/
	/*                  Initialize BLE                       */
	/*********************************************************/
	ble_stack_init();
	scheduler_init();
	gap_params_init();
	services_init();
	advertising_init();
	conn_params_init();
	sec_params_init();

	// // Start execution
	advertising_param_init();
	advertising_start();

	timers_init();
	timers_start();

	/*********************************************************/
	/*               Initialize Accelerometer                */
	/*********************************************************/
	initializeAccelerometer();
	initializeDataBank(true, false, false);

	/*********************************************************/
	/*               Initialize Hall Effects                 */
	/*********************************************************/

	/*********************************************************/
	/*         Initialize PWM Driver Related Outputs         */
	/*                   Servos & Lights                     */
	/*********************************************************/
	//init i2c
	i2c_init();	

	//Setup and init PWM
	pca9685_init(&twi_instance, PWM0_ADDR);
	pca9685_init(&twi_instance, PWM1_ADDR);

	pca9685_setPWMFreq(52.0f, PWM0_ADDR);


	pca9685_setPWMFreq(52.0f, PWM1_ADDR);

	update_servos(bike);
	initializeLights();

	initializePinStatus();

	// Do not remove any of the create_state functions
	// We need them to fix an interrupt bug

	// destroy_state(bike);
	// bike = create_state();
	led_on(LED_1);
	/*********************************************************/
	/*                     Main Loop                         */
	/*********************************************************/
	while (1) {

		curr_time = get_millis();
		if(curr_time > 20000){
			led_off(LED_1);
		}
		/* GET DATA */
		/*****************************************************/
		/*     Button Press Update                           */
		/*****************************************************/
		// Get the latest button statuses and store locally
		/*button10 = getPinStatusClear(10);
		  button09 = getPinStatusClear(9);
		  button06 = getPinStatusClear(6);
		  button05 = getPinStatusClear(5);
		  button04 = getPinStatusClear(4);
		  button03 = getPinStatusClear(3);*/
		state_update_flags(bike);

		/*****************************************************/
		/*     Accelerometeter Data Update                   */
		/*****************************************************/
		// Get the latest accelerometer data & store locally
		if (accel_ready && curr_time) {
			// led_toggle(LED_0);
			populateAccelDataBank();
			accel_ready = false;
		}

		bool newAccelVal = grabAccelData(DATA_X, &curr_x_val, NULL);


		/* PROCESS DATA */
		/*****************************************************/
		/*     Turn Signal State Machine                     */
		/*****************************************************/
		// Determine what state the turn lights should be in
		btn_state_change_alt(bike);



		/*****************************************************/
		/*     Turn Signal State Machine                     */
		/*****************************************************/
		if(newAccelVal){
			light_act = do_state_action( curr_x_val );
		}

		/*****************************************************/
		/*     Calculate Velocity                            */
		/*****************************************************/
		//velocity and acceleration are updated, target gear set
		if(bike->flags[WHEEL_FLAG] || bike->flags[SHIFT_DOWN_FLAG] ||
				bike->flags[SHIFT_UP_FLAG]) {

			//led_toggle(LED_0);
			update_target_state(bike);
		}

		/* CONTROL HARDWARE */
		/*****************************************************/
		/*     Lighting Control                              */
		/*****************************************************/
		// turn on/off all lights as specified
		performLightAction(bike, light_act);

		// if(readAxisX() <=0){
		//     led_on(LED_0);
		// }else{
		//     led_off(LED_0);
		// }

		/*****************************************************/
		/*     Shifting Control                              */
		/*****************************************************/
		if(bike->flags[PEDAL_FLAG]) {
			// led_on(LED_1);
			update_servos(bike);
			// led_off(LED_1);
		}

		// update_servos(bike);

		/* transmit BLE data */
		app_sched_execute();


		/*****************************************************/
		/*     Manage power (do we need this?)               */
		/*****************************************************/

		// MESSES UP ACCELEROMETER DATA
		power_manage();
	}

	destroy_state(bike);

	return 0;
}

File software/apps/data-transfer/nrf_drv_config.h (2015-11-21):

/* Copyright (c) 2015 Nordic Semiconductor. All Rights Reserved.
 *
 * The information contained herein is property of Nordic Semiconductor ASA.
 * Terms and conditions of usage are described in detail in NORDIC
 * SEMICONDUCTOR STANDARD SOFTWARE LICENSE AGREEMENT.
 *
 * Licensees are granted free, non-transferable use of the information. NO
 * WARRANTY of ANY KIND is provided. This heading must NOT be removed from
 * the file.
 *
 */

#ifndef NRF_DRV_CONFIG_H
#define NRF_DRV_CONFIG_H

/* CLOCK */
#define CLOCK_CONFIG_XTAL_FREQ          NRF_CLOCK_XTALFREQ_16MHz
#define CLOCK_CONFIG_LF_SRC             NRF_CLOCK_LF_SRC_Xtal
#define CLOCK_CONFIG_LF_RC_CAL_INTERVAL RC_2000MS_CALIBRATION_INTERVAL
#define CLOCK_CONFIG_IRQ_PRIORITY       APP_IRQ_PRIORITY_LOW

/* GPIOTE */
#define GPIOTE_ENABLED 1

#if (GPIOTE_ENABLED == 1)
#define GPIOTE_CONFIG_USE_SWI_EGU false
#define GPIOTE_CONFIG_IRQ_PRIORITY APP_IRQ_PRIORITY_HIGH
#define GPIOTE_CONFIG_NUM_OF_LOW_POWER_EVENTS 32
#endif

/* TIMER */
#define TIMER0_ENABLED 0

#if (TIMER0_ENABLED == 1)
#define TIMER0_CONFIG_FREQUENCY    NRF_TIMER_FREQ_16MHz
#define TIMER0_CONFIG_MODE         TIMER_MODE_MODE_Timer
#define TIMER0_CONFIG_BIT_WIDTH    TIMER_BITMODE_BITMODE_32Bit
#define TIMER0_CONFIG_IRQ_PRIORITY APP_IRQ_PRIORITY_LOW

#define TIMER0_INSTANCE_INDEX      0
#endif

#define TIMER1_ENABLED 0

#if (TIMER1_ENABLED == 1)
#define TIMER1_CONFIG_FREQUENCY    NRF_TIMER_FREQ_16MHz
#define TIMER1_CONFIG_MODE         TIMER_MODE_MODE_Timer
#define TIMER1_CONFIG_BIT_WIDTH    TIMER_BITMODE_BITMODE_16Bit
#define TIMER1_CONFIG_IRQ_PRIORITY APP_IRQ_PRIORITY_LOW

#define TIMER1_INSTANCE_INDEX      (TIMER0_ENABLED)
#endif

#define TIMER2_ENABLED 0

#if (TIMER2_ENABLED == 1)
#define TIMER2_CONFIG_FREQUENCY    NRF_TIMER_FREQ_16MHz
#define TIMER2_CONFIG_MODE         TIMER_MODE_MODE_Timer
#define TIMER2_CONFIG_BIT_WIDTH    TIMER_BITMODE_BITMODE_16Bit
#define TIMER2_CONFIG_IRQ_PRIORITY APP_IRQ_PRIORITY_LOW

#define TIMER2_INSTANCE_INDEX      (TIMER1_ENABLED+TIMER0_ENABLED)
#endif

#define TIMER_COUNT (TIMER0_ENABLED + TIMER1_ENABLED + TIMER2_ENABLED)

/* RTC */
#define RTC0_ENABLED 0

#if (RTC0_ENABLED == 1)
#define RTC0_CONFIG_FREQUENCY    32678
#define RTC0_CONFIG_IRQ_PRIORITY APP_IRQ_PRIORITY_LOW
#define RTC0_CONFIG_RELIABLE     false

#define RTC0_INSTANCE_INDEX      0
#endif

#define RTC1_ENABLED 0

#if (RTC1_ENABLED == 1)
#define RTC1_CONFIG_FREQUENCY    32768
#define RTC1_CONFIG_IRQ_PRIORITY APP_IRQ_PRIORITY_LOW
#define RTC1_CONFIG_RELIABLE     false

#define RTC1_INSTANCE_INDEX      (RTC0_ENABLED)
#endif

#define RTC_COUNT                (RTC0_ENABLED+RTC1_ENABLED)

#define NRF_MAXIMUM_LATENCY_US 2000

/* RNG */
#define RNG_ENABLED 0

#if (RNG_ENABLED == 1)
#define RNG_CONFIG_ERROR_CORRECTION true
#define RNG_CONFIG_POOL_SIZE        8
#define RNG_CONFIG_IRQ_PRIORITY     APP_IRQ_PRIORITY_LOW
#endif

/* TWI */
#define TWI0_ENABLED 0

#if (TWI0_ENABLED == 1)
#define TWI0_CONFIG_FREQUENCY    NRF_TWI_FREQ_100K
#define TWI0_CONFIG_SCL          0
#define TWI0_CONFIG_SDA          1
#define TWI0_CONFIG_IRQ_PRIORITY APP_IRQ_PRIORITY_HIGH

#define TWI0_INSTANCE_INDEX      0
#endif

#define TWI1_ENABLED 1

#if (TWI1_ENABLED == 1)
#define TWI1_CONFIG_FREQUENCY NRF_TWI_FREQ_250K
#define TWI1_CONFIG_SCL          0
#define TWI1_CONFIG_SDA          1
#define TWI1_CONFIG_IRQ_PRIORITY APP_IRQ_PRIORITY_LOW

#define TWI1_INSTANCE_INDEX      (TWI0_ENABLED)
#endif

#define TWI_COUNT                (TWI0_ENABLED+TWI1_ENABLED)

/* QDEC */
#define QDEC_ENABLED 0

#if (QDEC_ENABLED == 1)
#define QDEC_CONFIG_REPORTPER    NRF_QDEC_REPORTPER_10
#define QDEC_CONFIG_SAMPLEPER    NRF_QDEC_SAMPLEPER_16384us
#define QDEC_CONFIG_PIO_A        1
#define QDEC_CONFIG_PIO_B        2
#define QDEC_CONFIG_PIO_LED      3
#define QDEC_CONFIG_LEDPRE       511
#define QDEC_CONFIG_LEDPOL       NRF_QDEC_LEPOL_ACTIVE_HIGH
#define QDEC_CONFIG_IRQ_PRIORITY APP_IRQ_PRIORITY_LOW
#define QDEC_CONFIG_DBFEN        false
#define QDEC_CONFIG_SAMPLE_INTEN false
#endif

/* LPCOMP */
#define LPCOMP_ENABLED 0

#if (LPCOMP_ENABLED == 1)
#define LPCOMP_CONFIG_REFERENCE    NRF_LPCOMP_REF_SUPPLY_FOUR_EIGHT
#define LPCOMP_CONFIG_DETECTION    NRF_LPCOMP_DETECT_DOWN
#define LPCOMP_CONFIG_IRQ_PRIORITY APP_IRQ_PRIORITY_LOW
#define LPCOMP_CONFIG_INPUT        NRF_LPCOMP_INPUT_0
#endif

/* WDT */
#define WDT_ENABLED 0

#if (WDT_ENABLED == 1)
#define WDT_CONFIG_BEHAVIOUR     NRF_WDT_BEHAVIOUR_RUN_SLEEP
#define WDT_CONFIG_RELOAD_VALUE  2000
#define WDT_CONFIG_IRQ_PRIORITY  APP_IRQ_PRIORITY_HIGH
#endif

#endif // NRF_DRV_CONFIG_H

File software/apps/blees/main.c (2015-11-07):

/*
 * Advertises Sensor Data
 */

// Standard Libraries
#include <stdint.h>
#include <stdbool.h>
#include <stdio.h>
#include <string.h>
#include "math.h"

// Nordic Libraries
#include "app_util.h"
#include "app_error.h"
#include "app_trace.h"
#include "app_scheduler.h"
#include "app_util_platform.h"
#include "app_timer.h"
#include "ble_advdata_parser.h"
#include "ble_conn_params.h"
#include "ble_hci.h"
#include "ble_hrs_c.h"
#include "ble_bas_c.h"
#include "ble_advdata.h"
#include "ble_gap.h"
#include "ble_gatts.h"
#include "ble_debug_assert_handler.h"
#include "ble.h"
#include "ble_db_discovery.h"
#include "ble_config.h"
#include "ble_ess.h"
#include "nordic_common.h"
#include "nrf.h"
#include "nrf_sdm.h"
#include "nrf_gpio.h"
#include "nrf_soc.h"
#include "nrf_gpiote.h"
#include "nrf_drv_config.h"
#include "nrf_drv_gpiote.h"
#include "nrf_error.h"
#include "nrf_assert.h"
#include "nrf_drv_twi.h"
#include "pstorage.h"
#include "pstorage_platform.h"
#include "softdevice_handler.h"

// Platform, Peripherals, Devices, Services
#include "smartbike.h"
#include "led.h"
#include "tsl2561.h"
#include "si7021.h"
#include "lps331ap.h"
#include "adxl362.h"
#include "spi_driver.h" // take this out eventually!

/*******************************************************************************
 *   DEFINES
 ******************************************************************************/

#define APP_BEACON_INFO_LENGTH      11

#define PIN_IN                      5

#define APP_GPIOTE_MAX_USERS        1                                              /**< Maximum number of users of the GPIOTE handler. */

#define DEAD_BEEF                   0xDEADBEEF                                     /**< Value used as error code on stack dump, can be used to identify stack location on stack unwind. */

#define UPDATE_RATE                 APP_TIMER_TICKS(1000, APP_TIMER_PRESCALER)

//Initial Pressure Parameters
#define INIT_PRES_DATA              456
#define PRES_TRIGGER_CONDITION      TRIG_FIXED_INTERVAL
#define PRES_TRIGGER_VAL_OPERAND    470
#define PRES_TRIGGER_VAL_TIME       APP_TIMER_TICKS(3000, APP_TIMER_PRESCALER)

//Initial Humidity Parameters
#define INIT_HUM_DATA               789
#define HUM_TRIGGER_CONDITION       TRIG_FIXED_INTERVAL
#define HUM_TRIGGER_VAL_OPERAND     799
#define HUM_TRIGGER_VAL_TIME        APP_TIMER_TICKS(3000, APP_TIMER_PRESCALER)

//Initial Temperature Parameters
#define INIT_TEMP_DATA              123
#define TEMP_TRIGGER_CONDITION      TRIG_FIXED_INTERVAL
#define TEMP_TRIGGER_VAL_OPERAND    156
#define TEMP_TRIGGER_VAL_TIME       APP_TIMER_TICKS(3000, APP_TIMER_PRESCALER)

//Initial Lux Parameters
#define INIT_LUX_DATA               789
#define LUX_TRIGGER_CONDITION       TRIG_FIXED_INTERVAL
#define LUX_TRIGGER_VAL_OPERAND     799
#define LUX_TRIGGER_VAL_TIME        APP_TIMER_TICKS(6000, APP_TIMER_PRESCALER)

//Initial Acceleration Parameters
#define INIT_ACC_DATA               789
#define ACC_TRIGGER_CONDITION       TRIG_FIXED_INTERVAL
#define ACC_TRIGGER_VAL_OPERAND     799
#define ACC_TRIGGER_VAL_TIME        APP_TIMER_TICKS(3000, APP_TIMER_PRESCALER)


// Maximum size is 17 characters, counting URLEND if used
// Main App
//#define PHYSWEB_URL     "goo.gl/tM8s2Y"
// Demo App (http://nuclear.eecs.umich.edu/public/ble/blees-demo/index.html)
#define PHYSWEB_URL     "goo.gl/xWppj1"

/*******************************************************************************
 *   STATIC AND GLOBAL VARIABLES
 ******************************************************************************/

uint8_t MAC_ADDR[6] = {0x00, 0x00, 0x30, 0xe5, 0x98, 0xc0};
nrf_drv_twi_t twi_instance = NRF_DRV_TWI_INSTANCE(1);

static ble_app_t                    app;
static ble_gap_adv_params_t         m_adv_params;
static ble_advdata_t                advdata;
static ble_ess_t                    m_ess;
static uint8_t                      m_beacon_info[APP_BEACON_INFO_LENGTH];
static uint16_t                     m_conn_handle = BLE_CONN_HANDLE_INVALID;     /**< Handle of the current connection. */

static app_timer_id_t               sample_timer;                                /**< Advertisement timer. */
static app_timer_id_t               m_pres_timer_id;                             /**< ESS Pressure timer. */
static app_timer_id_t               m_hum_timer_id;                              /**< ESS Humidity timer. */
static app_timer_id_t               m_temp_timer_id;                             /**< ESS Temperature timer. */
static app_timer_id_t               m_lux_timer_id;                              /**< ESS Lux timer. */
static app_timer_id_t               m_lux_wait_timer_id;                              /**< ESS Lux timer. */

static app_timer_id_t               m_acc_timer_id;                              /**< ESS Accelerometer timer. */

static bool                         m_ess_updating_advdata = false;
static bool                         switch_acc = false;

static bool PHYSWEB_MODE = false;

// Security requirements for this application.
static ble_gap_sec_params_t m_sec_params = 
{
    SEC_PARAM_BOND,
    SEC_PARAM_MITM,
    SEC_PARAM_IO_CAPABILITIES,
    SEC_PARAM_OOB,
    SEC_PARAM_MIN_KEY_SIZE,
    SEC_PARAM_MAX_KEY_SIZE,
};

static struct {
    uint32_t pressure;
    uint16_t humidity;
    int16_t temp;
    uint16_t light;
    uint8_t acceleration;
} m_sensor_info = {1.0f, 2.0f, 3.0f, 4.0f, 0.0f};

/*******************************************************************************
 *   FUNCTION PROTOTYPES
 ******************************************************************************/
static void advertising_start(void);
static void advertising_stop(void);
static bool update_advdata(void);
static void update_timers( ble_evt_t * p_ble_evt );
static void adv_physweb(void);

/*******************************************************************************
 *   HANDLERS AND CALLBACKS
 ******************************************************************************/
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

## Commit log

2015-10-19 GPIO pin assignments file created
2015-10-20 accelerometer working in blink/main.c timer handler
2015-10-20 Accelerometer stuff and makefile stuff
2015-10-20 fixed all the stupid shit with folders
    [main.c, nrf_drv_config.h]
2015-10-29 button tests in progress, compiling
2015-11-03 Encoder stuff we worked on, even though we're not using it anymore...
2015-11-03 Removed EncoderControl stuff causing building errors
    [main.c]
2015-11-03 gpio drivers coded, compiled, to be tested
2015-11-04 working on pwm
2015-11-05 coded complete gpio driver using GPIOTE_IRQHandler from nrf_drv_gpiote.c
2015-11-05 working accelerometer data ready interrupts
2015-11-06 pwm fully functional; rename platform/blees to platform/smartbike, may need to fix target in some apps/.../Makefile
    [main.c, pwm.c, smartbike.h]
2015-11-07 updated gpio interrupt temp stuff
2015-11-07 fixed gpio interrupt driver
    [gpio_driver.c, main.c]
2015-11-07 changed chips folder to drivers and updated Makefiles with this path
2015-11-07 updated pwm driver & working interrupt-based-pwm control
2015-11-07 added some accelerometer-gpio stuff
2015-11-08 fixed LED constant issue
    [main.c]
2015-11-08 Hall effects skeleton. Needs work and redesign
2015-11-08 working simple/inefficient accelerometer gpio tilt test for demo purposes only
2015-11-10 pcb should be done
    [BLEES_REVB_BOM.csv, MainAutobike.brd, MainAutobike.sch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]
2015-11-10 updated pcb, added pdfs
    [MainAutobike.brd, MainAutobike.sch]
2015-11-10 charles, look over hall effect please; checked rest of schematic and board
    [MainAutobike.brd, MainAutobike.sch]
2015-11-10 can change pwm via debounced button interrupts
2015-11-11 Created a driver to manage producing data from accelerometer with averaging
2015-11-12 fixed AccelDataDriver compile errors. made brake light test
    [main.c, nrf_drv_config.h]
2015-11-12 port interrupts working
2015-11-12 started template for gear shifting stuff
2015-11-13 final revision A of PCB
    [MainAutobike.brd, MainAutobike.sch]
2015-11-13 cam files for pcb
2015-11-13 wrong drill cam processor, must use eagle7 version when running in eagle7
2015-11-13 stupid gerbers
2015-11-13 generated gerbers with eagle v6
2015-11-13 no ground on POWER led... Tim...
    [MainAutobike.sch]
2015-11-13 zip files of gerbers
2015-11-14 updated to fix turn signal double button and toggle functionality
    [main.c]
2015-11-15 Arduino sketch for shifting controlled by hall effect. Took out brake lights becuase I have a cleaner way to do that, which avoids floats. Numbers still need slight tweaking. Works well in lab, needs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
    [shifting.ino]
2015-11-17 WORKING GPIO PORT INTERRUPTSSSSSSSSSSSSSSSSSSSSSSSSSSSSSSSSSS
2015-11-17 Fixed up LightControl file
    [LightControl.h]
2015-11-18 coded up light control. Need pwm code to be inserted where stated
2015-11-20 Changed port gpio from 1 to 32 in all directories. updated gpio driver to work with port events.
2015-11-20 Small driver for Hall Effect handlers and speed calculations
2015-11-20 ServoControl has ported code form Arduino Sketch. LightControl.h is fixed
    [LightControl.h, ServoControl.c, main.c]
2015-11-20 Added pwm driver functions to both LightControl and ServoControl. Fixed a few visual bugs and compiles
    [LightControl.c, LightControl.h, ServoControl.c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]
2015-11-20 starting to test current functionality on nordic
2015-11-20 added pwm and servo setup
2015-11-20 GPIO driver tested and works perfectly
2015-11-20 compiles after gpio driver changes
2015-11-21 rearranged driver files and started work on main smartbike app
2015-11-21 Fixed main to use gpio driver
    [main.c]
2015-11-22 added timer api for smartbike - includes get millisecond
2015-11-23 smartbike main changes to reflect pins, and led debugging. Also, there's a real flying bug in the lab. Watch out.
    [main.c]
2015-11-23 updated main timers stuff
2015-11-24 timer stuff has changed. main in smartbike not working.
    [BikeTimers.h]
2015-11-24 servo speeds being tested. We found out we need to do overshoot with timer. Talk to Alan or Dinker
    [ServoControl.c]
2015-11-24 some updates to accelerometer turn control driver and test
2015-11-24 fixed accel turn control driver
    [AccelTurnControl.h]
2015-11-24 updated pins for accel SPI driver
2015-11-24 changed pwm to use i2c address as param
2015-11-24 PWM addresses for smartbike go in smartbike.h in platform/
2015-11-25 shifting servos using new PWM api
2015-11-25 light control using latest PWM api
2015-11-25 lightcontrol changed defines for pwm addresses to make them more readable
2015-11-25 prototype coded
2015-11-27 redesigned the light drivers
    [LightControl.c, LightControl.h]
2015-11-28 Light Action worked for a long while until communication with PWM stopped working. Need to find out problem with test_lights/main.c
    [LightControl.c, LightControl.h, main.c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]
2015-11-28 added tested code form turn signals, accel data drivers, and light output
2015-11-29 Changed how we access pin mappings and flags
2015-11-29 changed how smartbike handles pin mappings
2015-12-01 Fixed my stupid light bugs
    [LightControl.c, LightControl.h]
2015-12-02 Bug fixed to allow gpio driver to work with our main
    [gpio_driver.c]
2015-12-02 made correct pin mappings
    [main.c]
2015-12-03 created init function to avoid forgetting to set axis polling
    [main.c]
2015-12-03 fixed a bug where a rear light state was incorrect
    [LightControl.h]
2015-12-03 light actions and control (turn, rear, gears) are currently integrated, tested, and working with smartbike main.
2015-12-03 changed pwm values
2015-12-04 abstracted some new turn hall effect control stuff (NEED TO CHANGE PINS)
2015-12-05 added accel timers
2015-12-05 example for using accel timer; all you have to do is call the set_accel_handler function with a function as the parameter before calling timers_init
2015-12-05 All our timers added
2015-12-07 app scheduler tests(may be useful sometime); ble advertising with timers
2015-12-07 added timer stuff for accel and light toggle
2015-12-07 changed pwm values for lgiht output
2015-12-07 working turn control with accelerometer and hall effects
2015-12-08 ble works with multiple timers
2015-12-09 ble stuff ported to main and RAM-stack overflow issue fixed by removing assert library
    [AccelTurnControl.h, BikeTimers.h, main.c]
2015-12-09 changed servo arrays to appropriate numbers, added a check to make sure we cant attempt to shift to a gear that indexes out of the array.
2015-12-09 fixed ble timer by disabling turn signal timer (its too slow)
    [BikeTimers.h, main.c]
2015-12-10 scaled get millis timer to work with BLE timer
2015-12-10 make update gear check for manual or auto mode
2015-12-10 changes to bikestate shifting pins. Changes to manual shifting in hall effect control
2015-12-10 incremental changes. No more light timer. integrated into accel timer with scaler. all functionality working.
2015-12-12 Fixed eagle shematic merge conflict
    [MainAutobike.sch]

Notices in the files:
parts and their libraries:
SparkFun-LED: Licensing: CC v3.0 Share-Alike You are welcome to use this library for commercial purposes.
